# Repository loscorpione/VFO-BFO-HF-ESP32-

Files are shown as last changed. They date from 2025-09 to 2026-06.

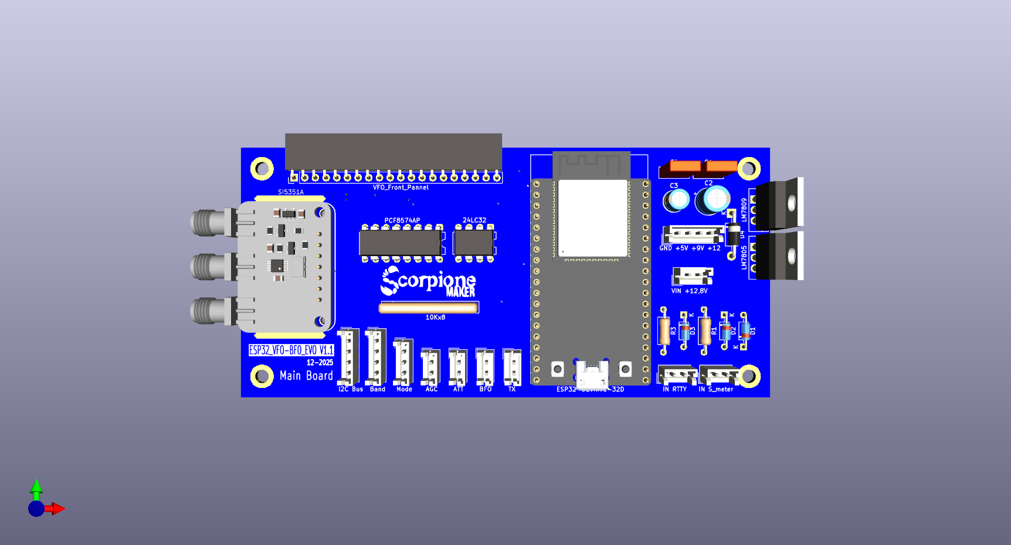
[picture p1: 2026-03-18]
VFO BFO Si5351 Circuit/VFO BFO Si5351 - Main Board/Immage/Mainboard.png

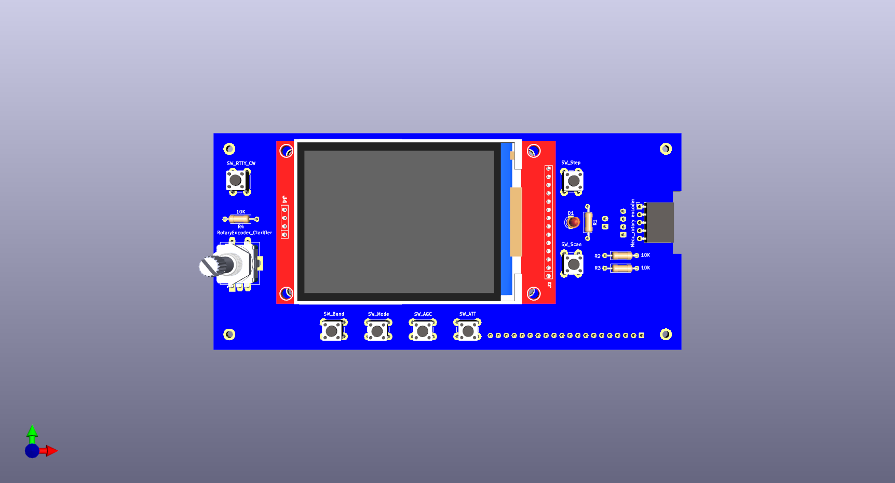
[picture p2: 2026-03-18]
VFO BFO Si5351 Circuit/VFO BFO Si5351 - Front Pannel/Immagin/Front Pannel.png

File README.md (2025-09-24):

VFO Basato su Si5351 e gestito da un ESP32 Devkit V1 attualmente il progetto è in costruzione.

Pensato principalmente per un ricevitore ma non è detto che in futuro venga implementata la funzione di trasmissione.

il progetto definitivo dovrà prevedere:
  -VFO con IF 455Khz 
  -BFO per la demodulazione di LSB, USB, CW con regolazione del "pitch" per un migliore adattamento
  -Uscita binaria a 2 bit indicante la modalità LSB, USB, CW, AM
  -Uscita binaria a 4 bit indicante la banda utilizzata per la selezione dell'opportuno BPF.
  -Eventuale decodifica per RTTY, CW on board
  -Memorizzazione su eeprom esterna o Fram 
  -Web server per la gestione remota tramite wi-fi ed eventuale proiezione in rete

I comandi sono:
  -ENCODER: come selettore di frequenza.
  -STEP: per cambio frequenza (10Hz, 100Hz, 1KHz, 10KHZ) con indicazione su display.
  -BAND: per la selezione della banda con indicazione su display delle bande radioamatoriali e non.
  -MODE: seleziona il tipo di demodulazione, con indicazione su pin binaria.
  -ATT: selettore attenuatore

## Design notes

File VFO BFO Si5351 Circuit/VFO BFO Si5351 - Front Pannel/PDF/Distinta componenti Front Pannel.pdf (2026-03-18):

Reference | Qty | Value | Footprint
D1 | | 1 LED | LED_THT:LED_D3.0mm
J1 | | 1 LED | Connector_JST:JST_EH_B2B-EH-A_1x02_P2.50mm_Vertical
J2 | | 1 Optical Rotary Encoder | Connector_JST:JST_EH_B4B-EH-A_1x04_P2.50mm_Vertical
J3 | | 1 Mecc_rotary encoder | Connector_PinSocket_2.54mm:PinSocket_1x05_P2.54mm_Horizontal
J4 | | 1 VFO_Front_Pannel | Connector_PinHeader_2.54mm:PinHeader_1x20_P2.54mm_Vertical
R1 | | 1 R=Vled-2/20mA | Resistor_THT:R_Axial_DIN0207_L6.3mm_D2.5mm_P10.16mm_Horizontal
R2,R3,R4 | | 3 10K | Resistor_THT:R_Axial_DIN0207_L6.3mm_D2.5mm_P10.16mm_Horizontal
SW1 | | 1 RotaryEncoder_Clarifier | -Rotary_Encoder:RotaryEncoder_Alps_EC12E-Switch_Vertical_H20mm
SW2 | | 1 SW_Band | Button_Switch_THT:SW_PUSH_6mm
SW3 | | 1 SW_Mode | Button_Switch_THT:SW_PUSH_6mm
SW4 | | 1 SW_AGC | Button_Switch_THT:SW_PUSH_6mm
SW5 | | 1 SW_ATT | Button_Switch_THT:SW_PUSH_6mm
SW6 | | 1 SW_Scan | Button_Switch_THT:SW_PUSH_6mm
SW7 | | 1 SW_Step | Button_Switch_THT:SW_PUSH_6mm
SW8 | | 1 SW_RTTY_CW | Button_Switch_THT:SW_PUSH_6mm
U1 | | 1 Ili9341_Module_TFT_320x240_Touch | -Display_Graphic:DISPLAY_TFT_ILI9341_2.8

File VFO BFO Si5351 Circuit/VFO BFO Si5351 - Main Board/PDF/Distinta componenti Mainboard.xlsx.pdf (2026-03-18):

Reference | Qty | Value | Footprint
C1,C4 | | 2 100nF | Capacitor_THT:C_Rect_L7.0mm_W2.5mm_P5.00mm
C2 | | 1 220uF 16V | Capacitor_THT:CP_Radial_D6.3mm_P2.50mm
C3 | | 1 100uF 10V | Capacitor_THT:CP_Radial_D5.0mm_P2.00mm
D1 | | 1 1N4148 | Diode_THT:D_DO-35_SOD27_P7.62mm_Horizontal
D2,D3 | | 2 DZ 3.3V | Diode_THT:D_DO-35_SOD27_P7.62mm_Horizontal
D4 | | 1 1N4007 | Diode_THT:D_DO-41_SOD81_P10.16mm_Horizontal
J1 | | 1 I2C Bus | Connector_JST:JST_EH_B4B-EH-A_1x04_P2.50mm_Vertical
J2 | | 1 Band | Connector_JST:JST_EH_B4B-EH-A_1x04_P2.50mm_Vertical
J3 | | 1 Mode | Connector_JST:JST_EH_B3B-EH-A_1x03_P2.50mm_Vertical
J4 | | 1 AGC | Connector_JST:JST_EH_B2B-EH-A_1x02_P2.50mm_Vertical
J5 | | 1 ATT | Connector_JST:JST_EH_B2B-EH-A_1x02_P2.50mm_Vertical
J6 | | 1 BFO | Connector_JST:JST_EH_B2B-EH-A_1x02_P2.50mm_Vertical
J7 | | 1 TX | Connector_JST:JST_EH_B2B-EH-A_1x02_P2.50mm_Vertical
J8 | | 1 IN RTTY | Connector_JST:JST_EH_B2B-EH-A_1x02_P2.50mm_Vertical
J9 | | 1 IN S_meter | Connector_JST:JST_EH_B2B-EH-A_1x02_P2.50mm_Vertical
J10 | | 1 VIN +12,8V | Connector_JST:JST_EH_B2B-EH-A_1x02_P2.50mm_Vertical
J11 | | 1 GND +5V +9V +12 | Connector_JST:JST_EH_B4B-EH-A_1x04_P2.50mm_Vertical
J12 | | 1 Front_Pannel | Connector_PinHeader_2.54mm:PinHeader_1x20_P2.54mm_Vertical
M1 | | 1 Si5351A module | Periferial_Module:si5351a_Module
R1,R3 | | 2 1K | Resistor_THT:R_Axial_DIN0207_L6.3mm_D2.5mm_P10.16mm_Horizontal
RN1 | | 1 10Kx8 | Resistor_THT:R_Array_SIP9
U1 | | 1 ESP32-DEVKITC-32D | -ESP32_Module:MODULE_ESP32-DEVKITC-32D
U2 | | 1 PCF8574AP | Package_DIP:DIP-16_W7.62mm
U3 | | 1 LM7809 | Package_TO_SOT_THT:TO-220-3_Vertical
U4 | | 1 LM7805 | Package_TO_SOT_THT:TO-220-3_Vertical
U5 | | 1 24LC32 | Package_DIP:DIP-8_W7.62mm

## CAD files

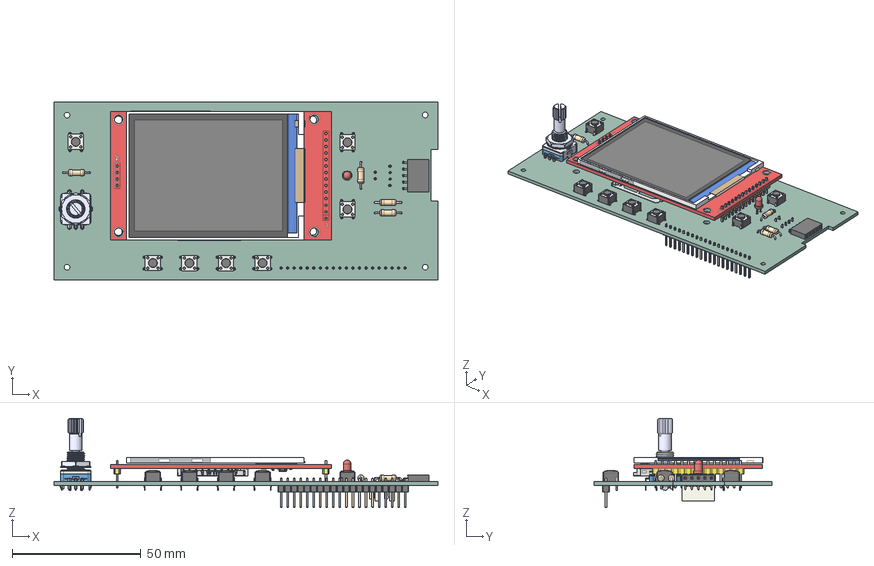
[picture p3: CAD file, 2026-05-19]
VFO BFO Si5351 Circuit/VFO BFO Si5351 - Front Pannel/Front Pannel.step
149.4 x 69.2 x 34.7 mm
R_Axial_DIN0207_L6.3mm_D2.5mm_P10.16mm_Horizontal x 4
LED_D3.0mm
SW_PUSH_6mm x 7
PinSocket_1x05_P2.54mm_Horizontal
EC11-Shaft-K
EC11-Housing-THT
2.8 LCD TFT Module - Without Glass
0603 Resistor x 6
0603 Capacitor x 2
SOT23-3 x 2
2.8in TFT(Without Glass)- Tucked Cable
JST_EH_B2B-EH-A_1x02_P2.50mm_Vertical
PinHeader_1x20_P2.54mm_Vertical
JST_EH_B4B-EH-A_1x04_P2.50mm_Vertical
Front Pannel_PCB

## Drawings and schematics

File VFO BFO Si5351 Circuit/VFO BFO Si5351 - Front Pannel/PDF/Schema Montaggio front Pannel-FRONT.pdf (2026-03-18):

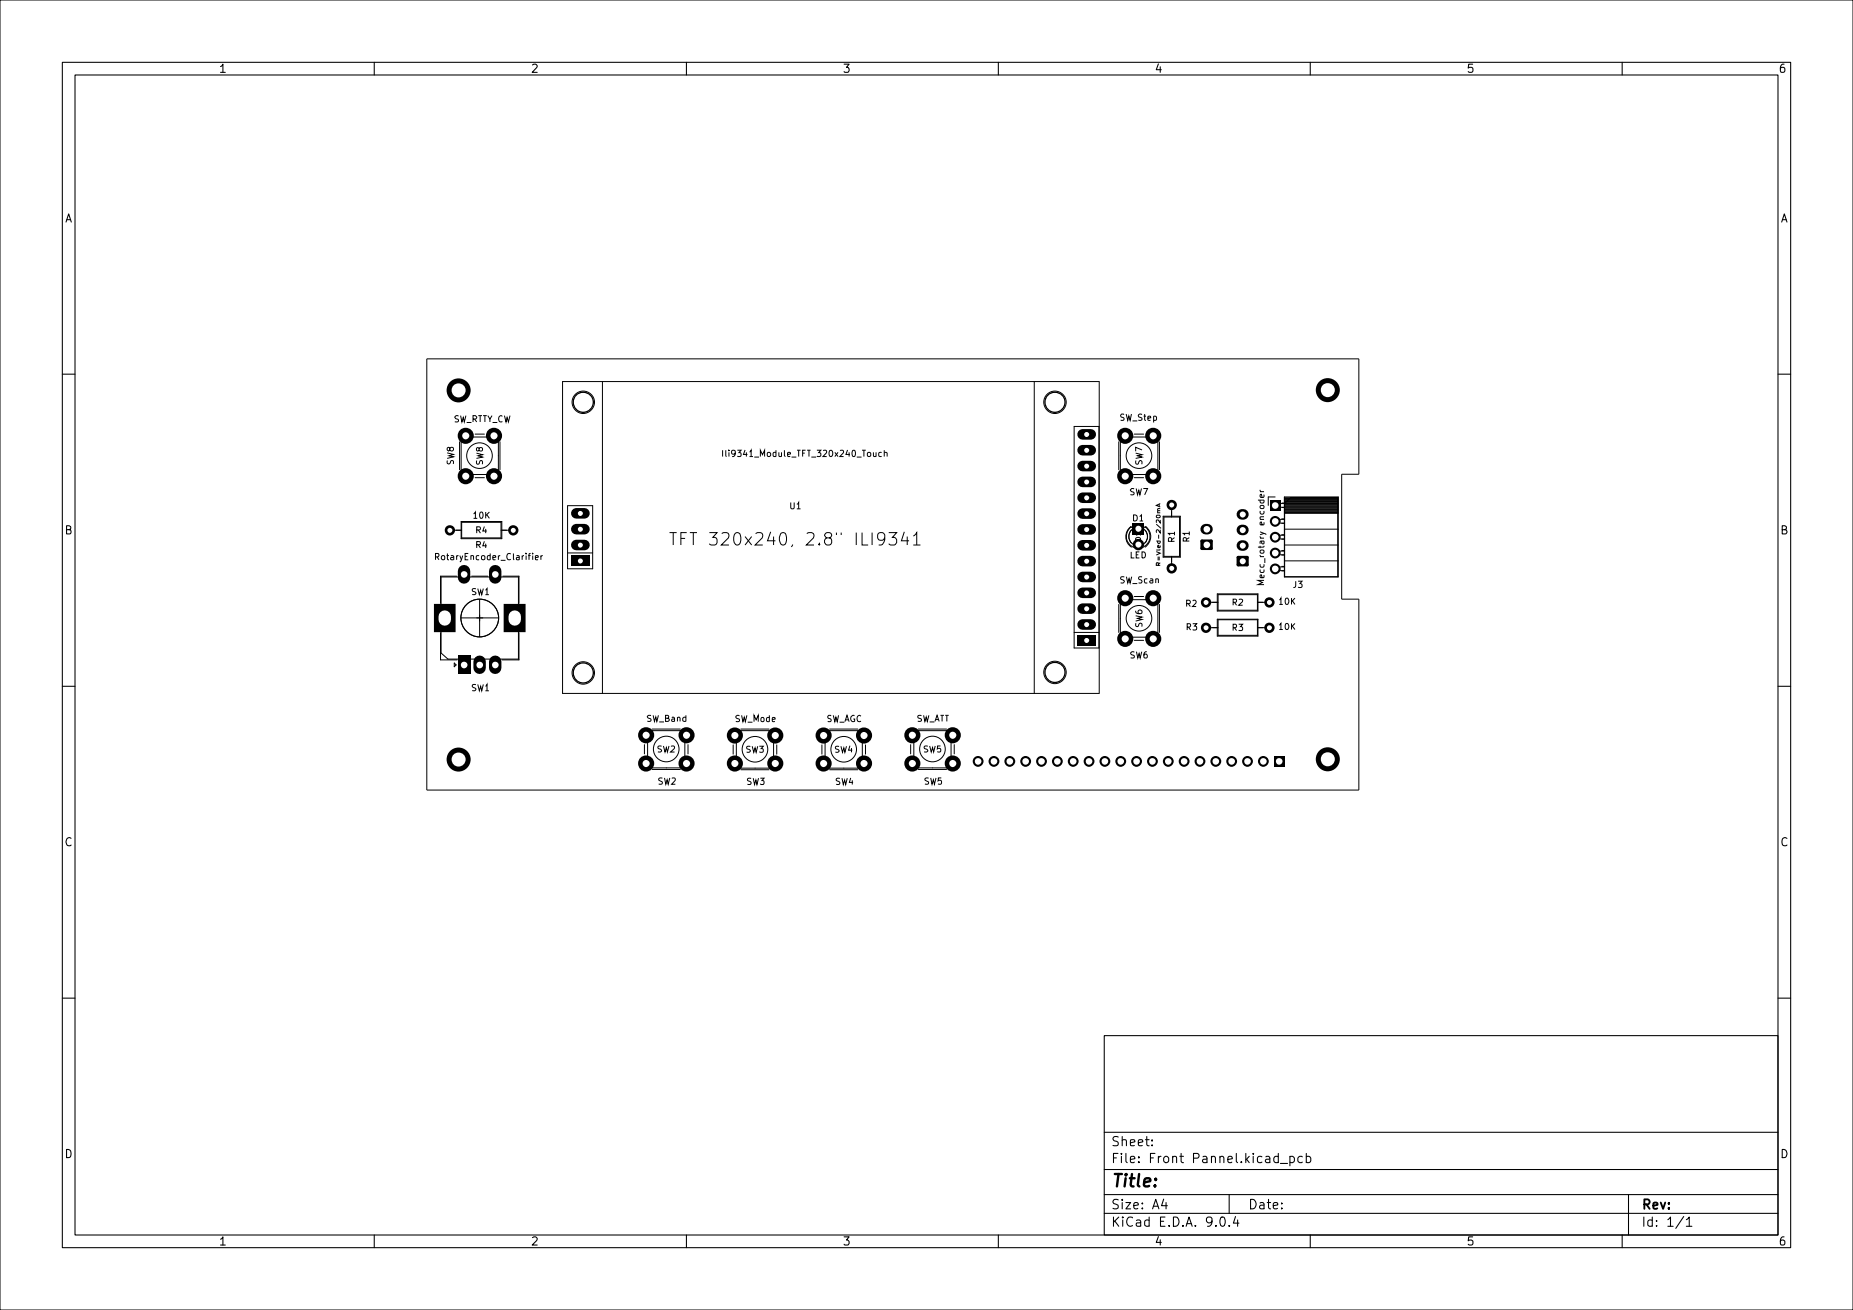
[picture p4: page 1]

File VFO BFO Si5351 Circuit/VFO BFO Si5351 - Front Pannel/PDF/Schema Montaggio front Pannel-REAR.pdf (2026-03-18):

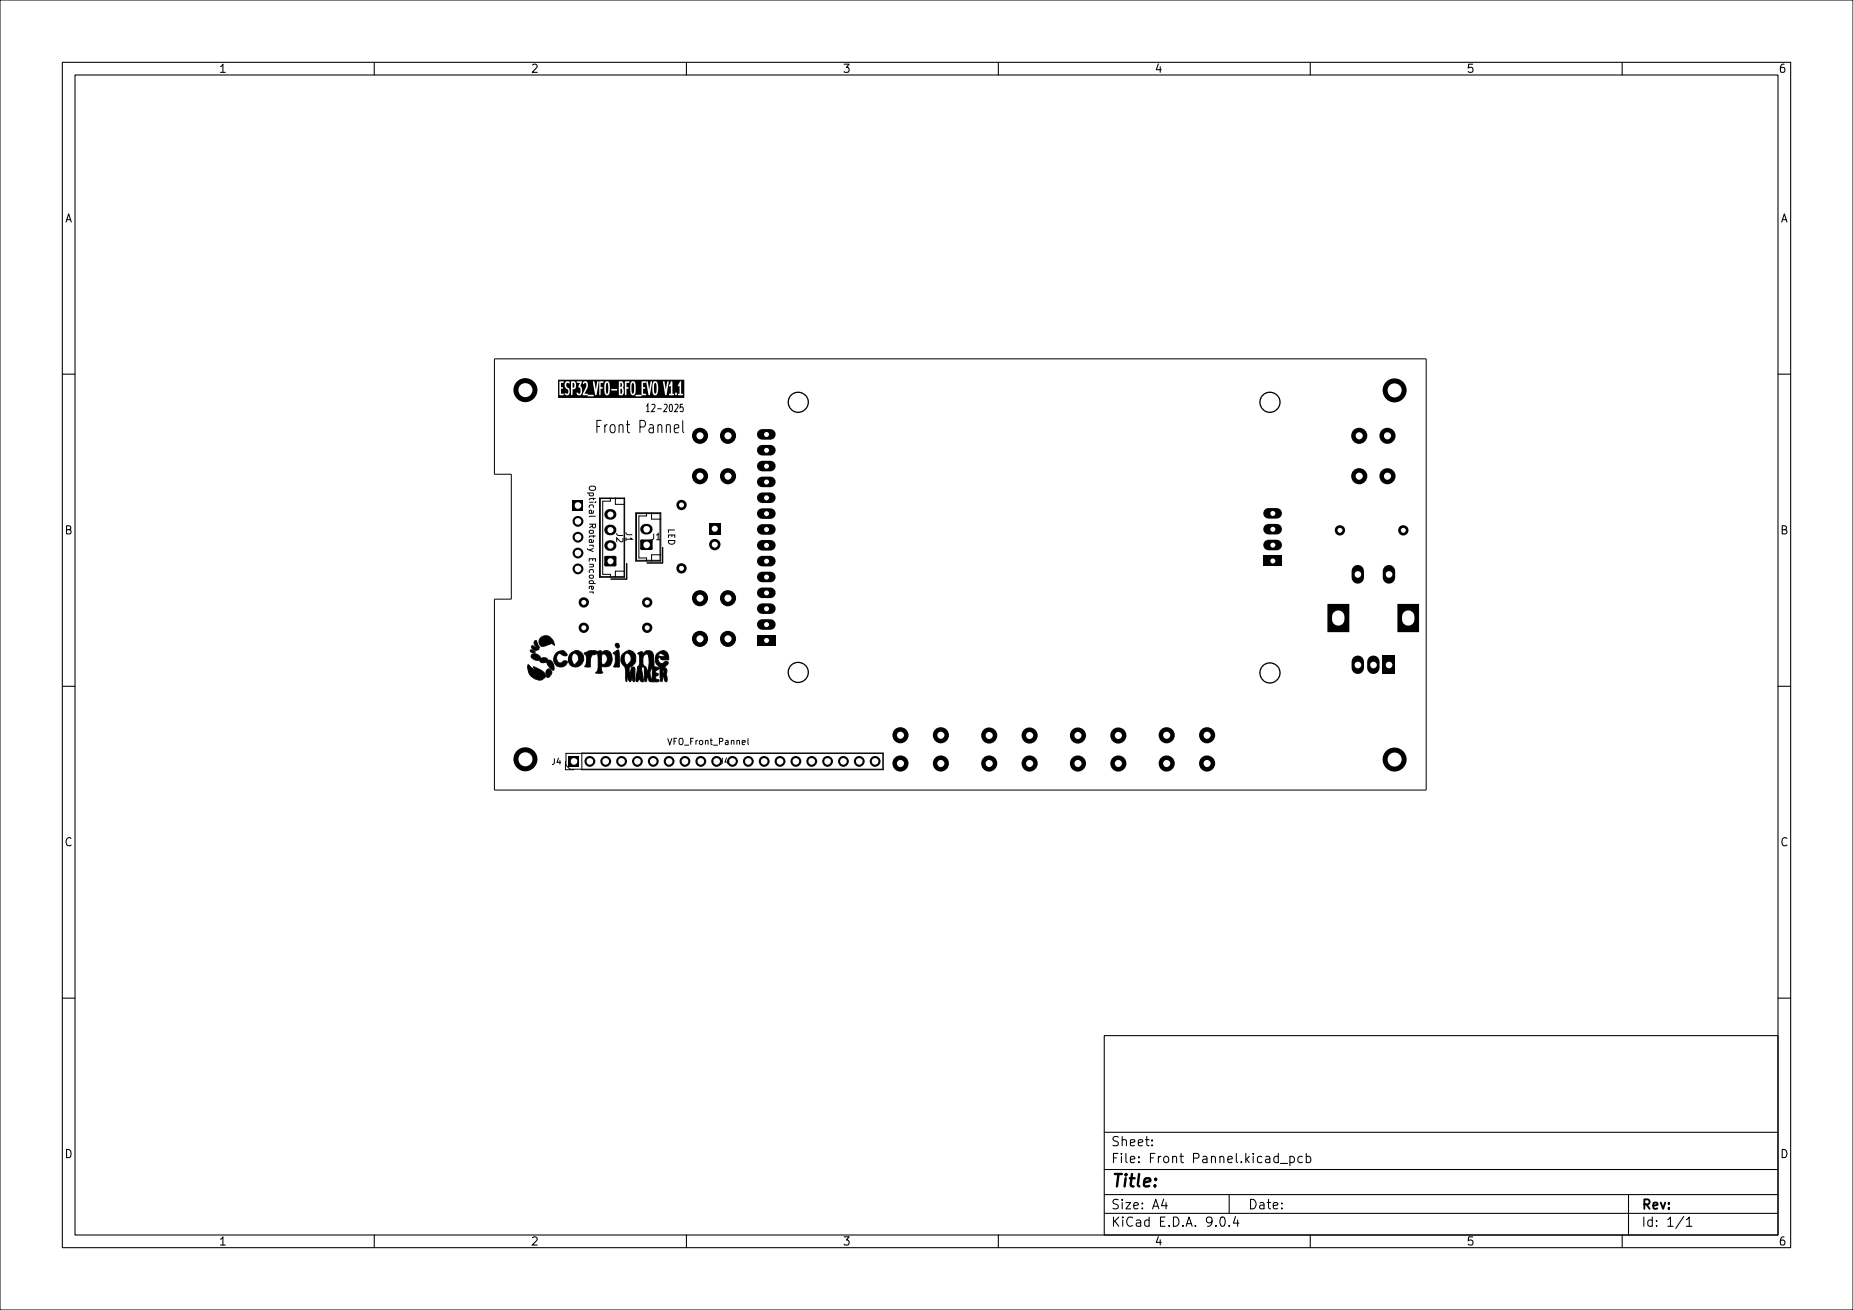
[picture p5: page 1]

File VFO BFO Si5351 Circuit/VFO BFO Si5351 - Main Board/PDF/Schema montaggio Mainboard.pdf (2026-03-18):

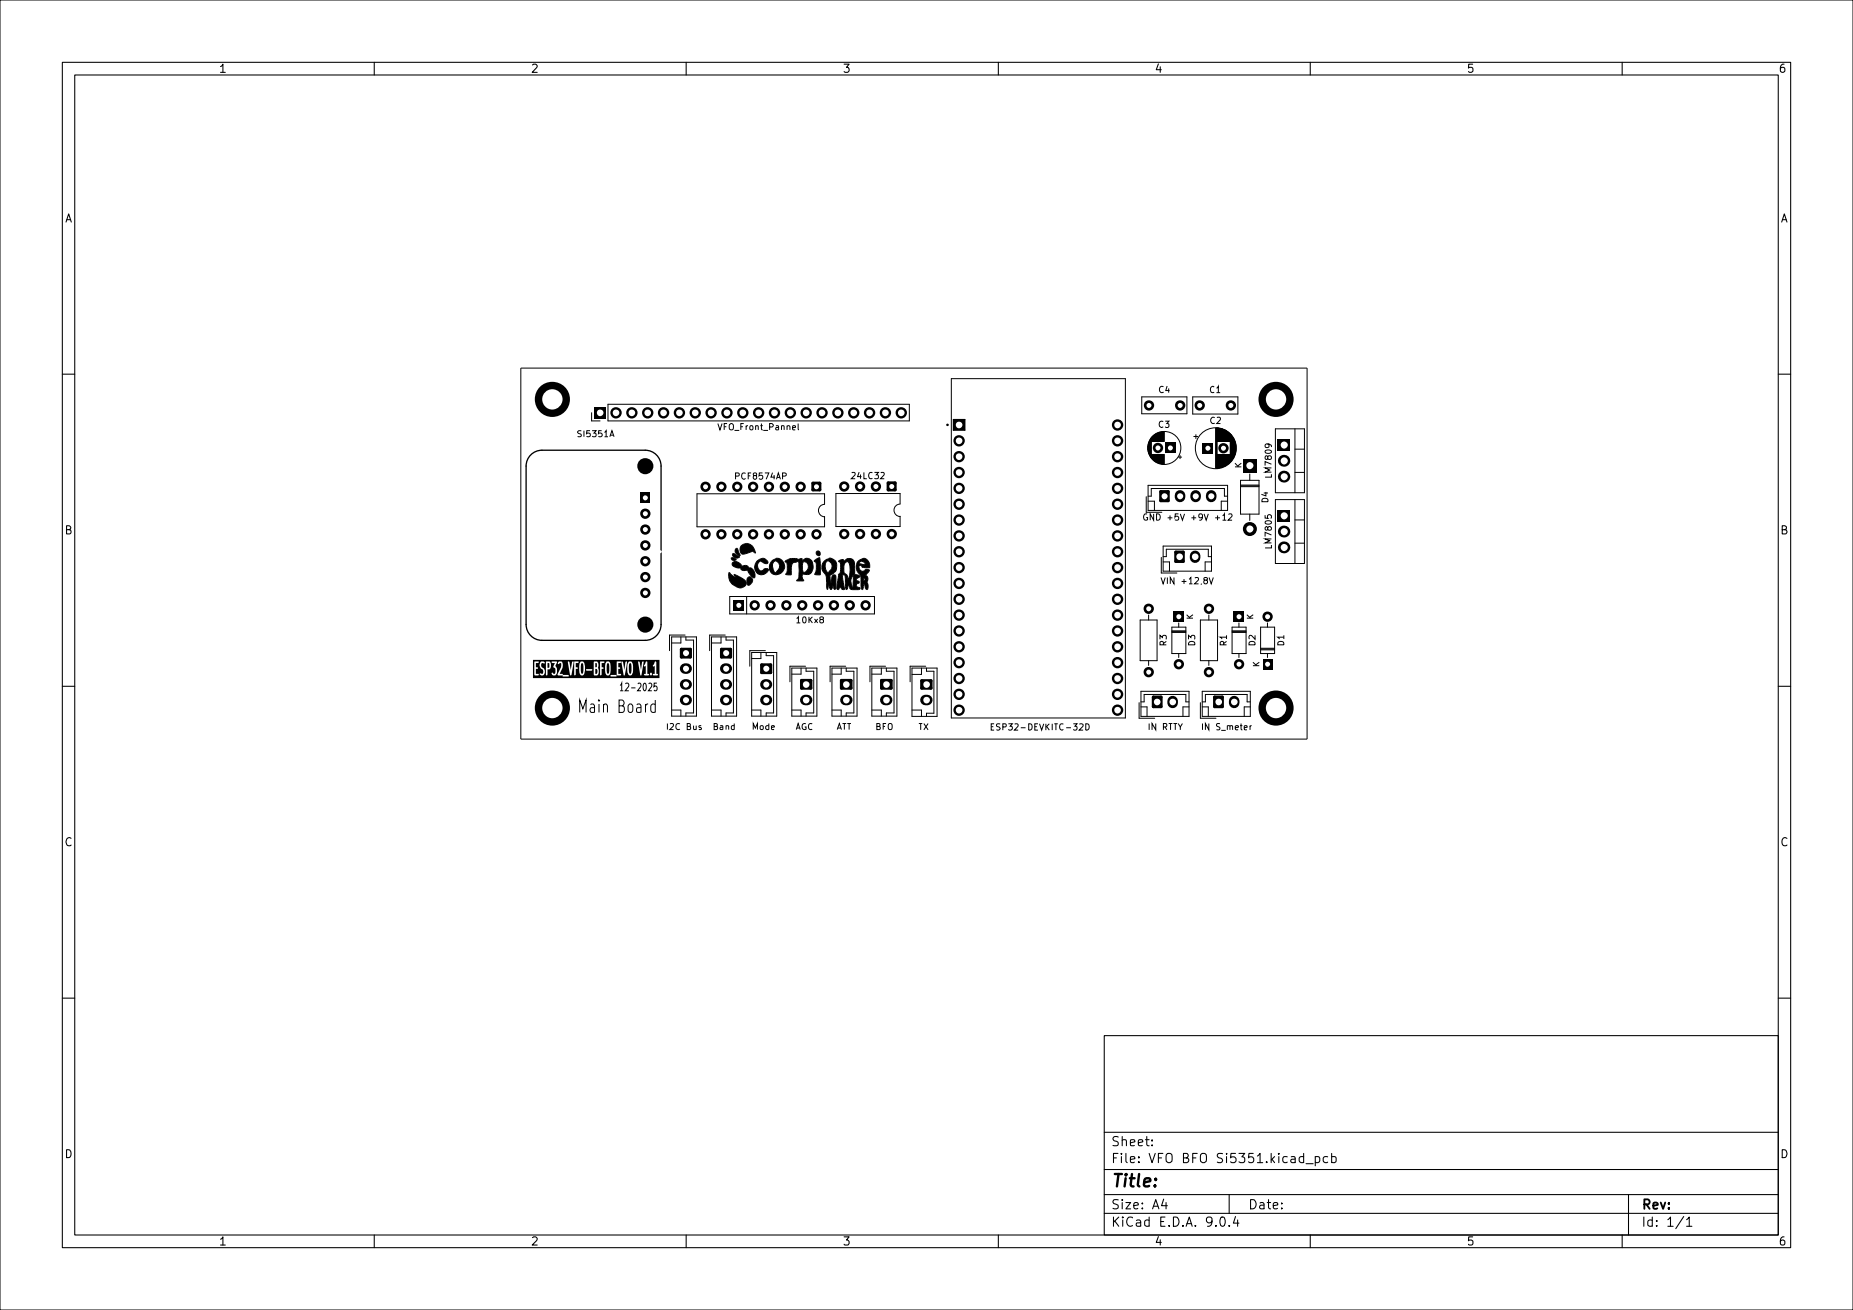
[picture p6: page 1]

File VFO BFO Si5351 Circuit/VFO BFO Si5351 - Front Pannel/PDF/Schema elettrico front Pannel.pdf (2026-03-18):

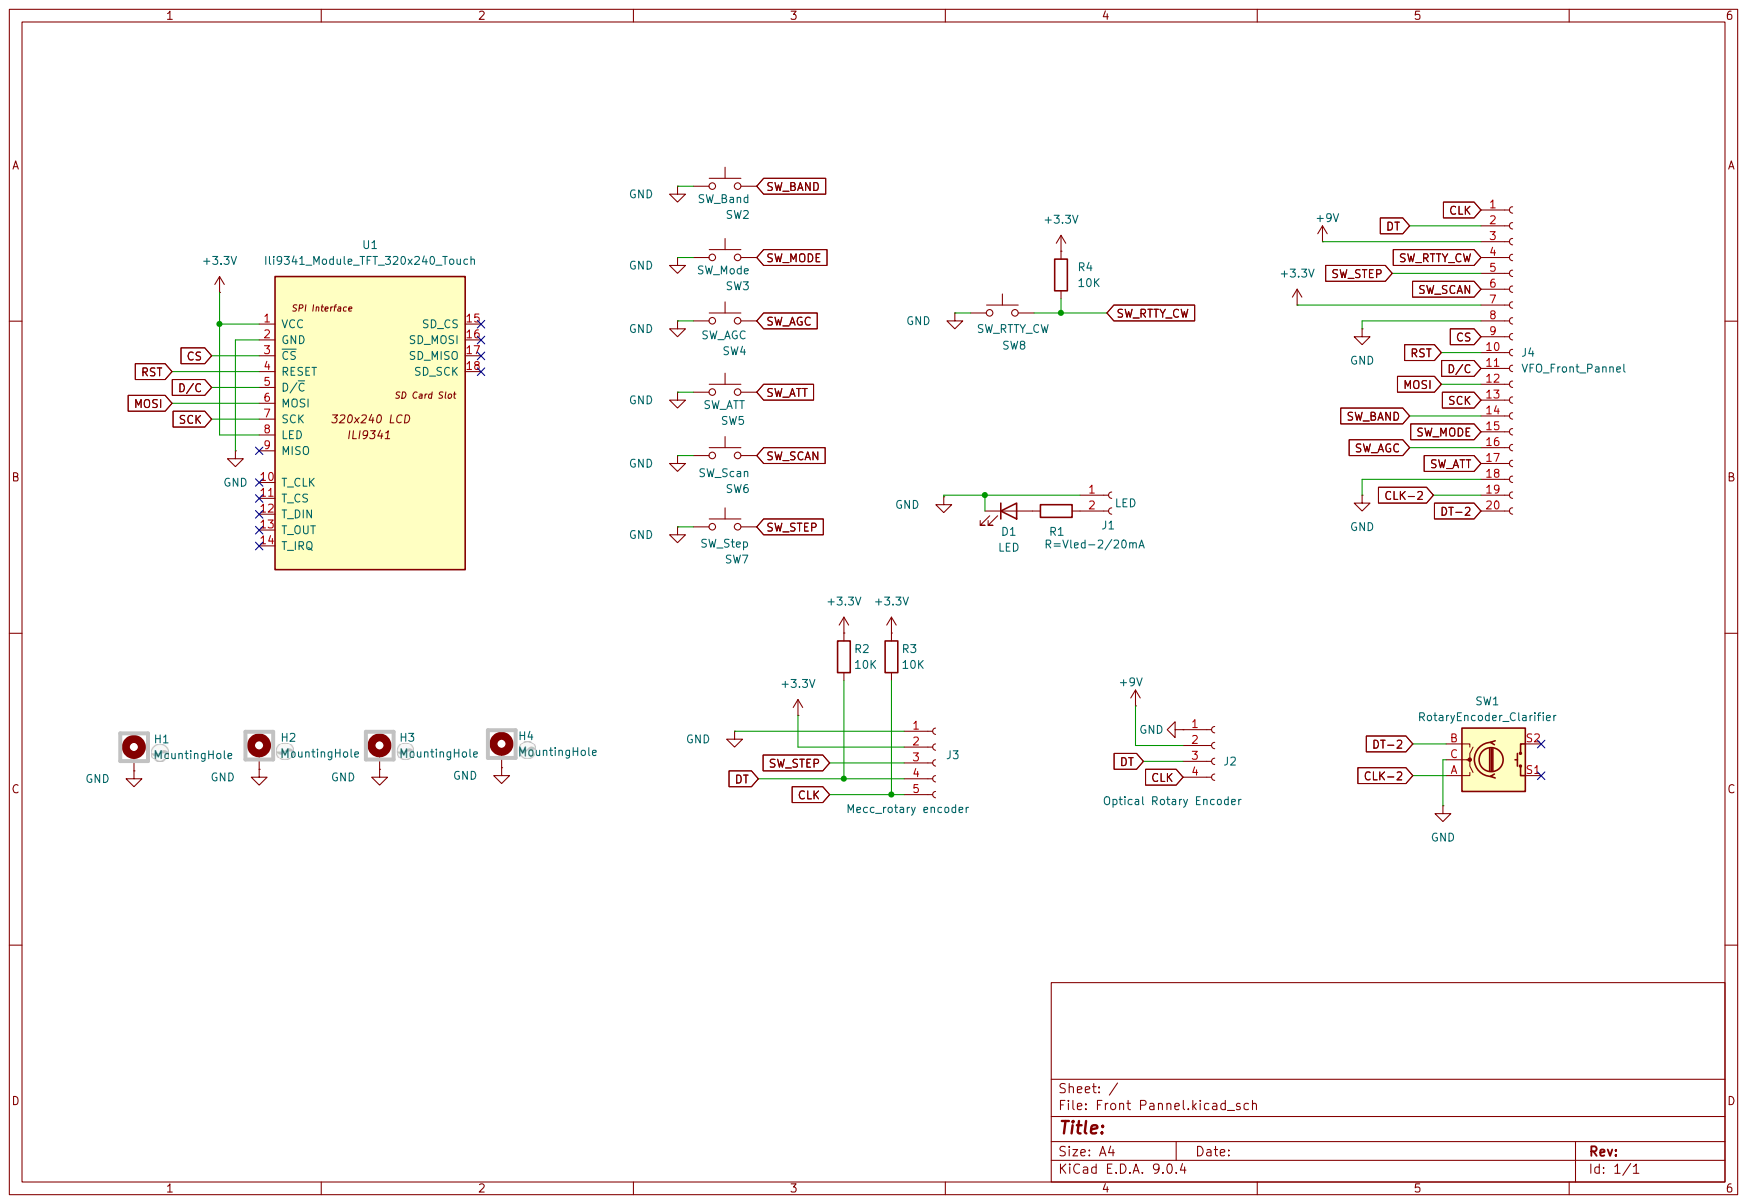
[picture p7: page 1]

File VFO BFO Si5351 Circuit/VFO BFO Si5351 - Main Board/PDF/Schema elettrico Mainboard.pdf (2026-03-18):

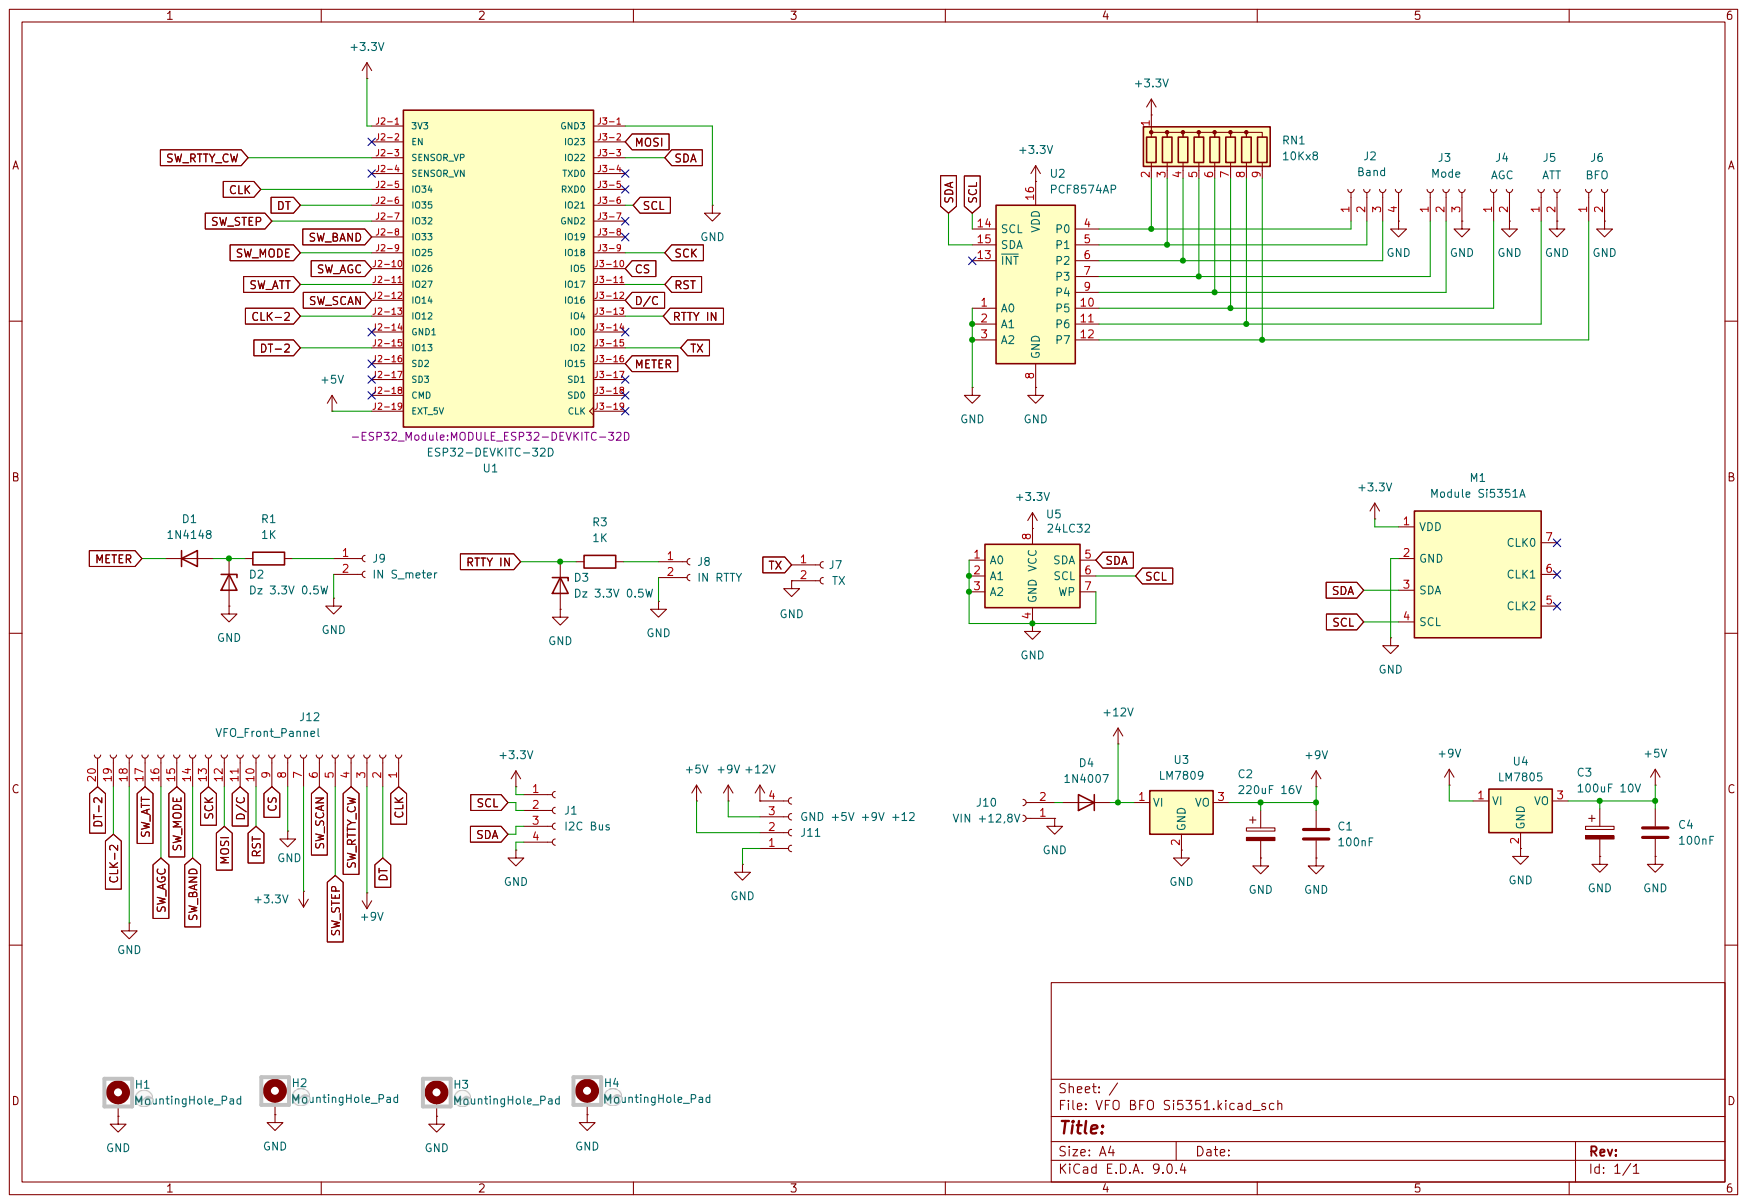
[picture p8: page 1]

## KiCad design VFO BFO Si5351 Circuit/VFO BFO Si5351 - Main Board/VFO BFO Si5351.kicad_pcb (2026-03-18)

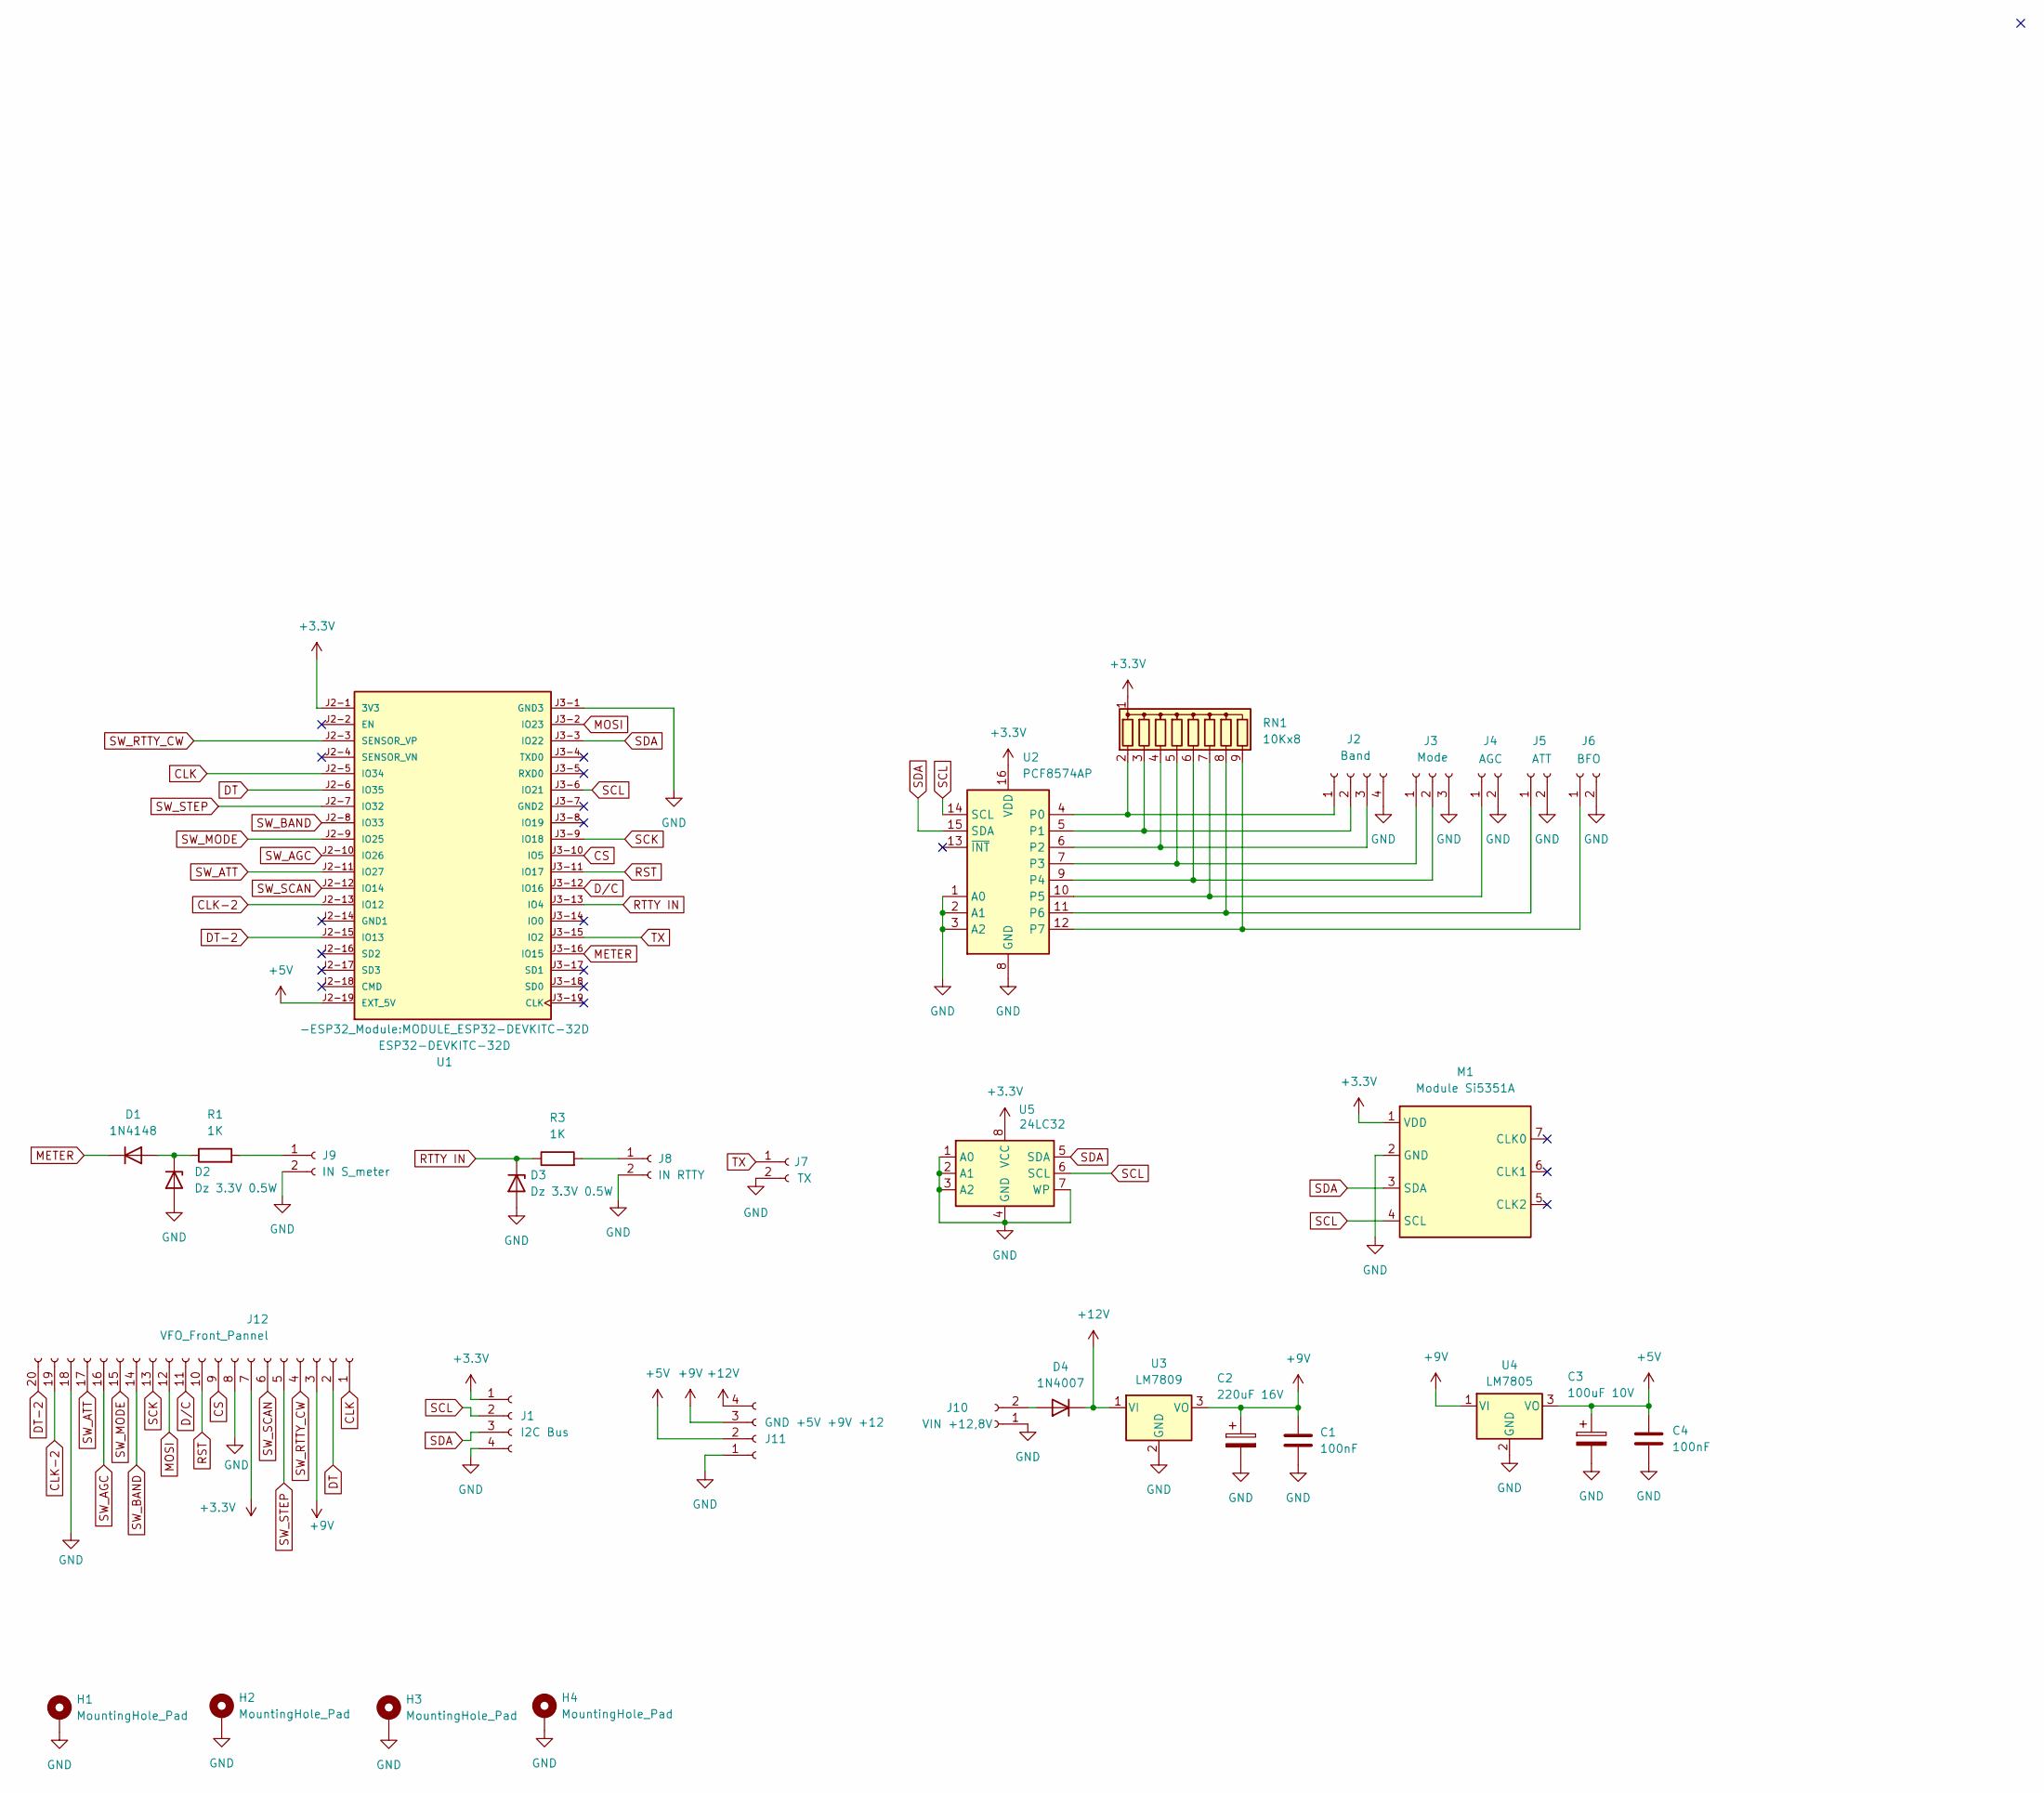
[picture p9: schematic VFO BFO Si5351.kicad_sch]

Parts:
C1, C4: 100nF; C_Rect_L7.0mm_W2.5mm_P5.00mm
C2: 220uF 16V; CP_Radial_D6.3mm_P2.50mm
C3: 100uF 10V; CP_Radial_D5.0mm_P2.00mm
D1: 1N4148; D_DO-35_SOD27_P7.62mm_Horizontal
D2, D3: Dz 3.3V 0.5W; D_DO-35_SOD27_P7.62mm_Horizontal
D4: 1N4007; D_DO-41_SOD81_P10.16mm_Horizontal
H1, H2, H3, H4: MountingHole_Pad; MountingHole_3.2mm_M3_DIN965_Pad_TopBottom
J1: I2C Bus; JST_EH_B4B-EH-A_1x04_P2.50mm_Vertical
J2: Band; JST_EH_B4B-EH-A_1x04_P2.50mm_Vertical
J3: Mode; JST_EH_B3B-EH-A_1x03_P2.50mm_Vertical
J4: AGC; JST_EH_B2B-EH-A_1x02_P2.50mm_Vertical
J5: ATT; JST_EH_B2B-EH-A_1x02_P2.50mm_Vertical
J6: BFO; JST_EH_B2B-EH-A_1x02_P2.50mm_Vertical
J7: TX; JST_EH_B2B-EH-A_1x02_P2.50mm_Vertical
J8: IN RTTY; JST_EH_B2B-EH-A_1x02_P2.50mm_Vertical
J9: IN S_meter; JST_EH_B2B-EH-A_1x02_P2.50mm_Vertical
J10: VIN +12,8V; JST_EH_B2B-EH-A_1x02_P2.50mm_Vertical
J11: GND +5V +9V +12; JST_EH_B4B-EH-A_1x04_P2.50mm_Vertical
J12: VFO_Front_Pannel; PinHeader_1x20_P2.54mm_Vertical
M1: Module Si5351A; si5351a_Module
R1, R3: 1K; R_Axial_DIN0207_L6.3mm_D2.5mm_P10.16mm_Horizontal
RN1: 10Kx8; R_Array_SIP9
U1: ESP32-DEVKITC-32D; MODULE_ESP32-DEVKITC-32D; PARTREV V4
U2: PCF8574AP; DIP-16_W7.62mm
U3: LM7809; TO-220-3_Vertical
U4: LM7805; TO-220-3_Vertical
U5: 24LC32; DIP-8_W7.62mm

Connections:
+3.3V: J1.1, J12.7, M1.1 (VDD), RN1.1 (common), U1.J2-1 (3V3), U2.16 (VDD), U5.8 (VCC)
+5V: C3.1, C4.1, J11.2, U1.J2-19 (EXT_5V), U4.3 (VO)
+9V: C1.1, C2.1, J11.3, J12.3, U3.3 (VO), U4.1 (VI)
+12V: D4.1 (K), J11.4, U3.1 (VI)
CLK: J12.1, U1.J2-5 (IO34)
CLK-2: J12.19, U1.J2-13 (IO12)
CS: J12.9, U1.J3-10 (IO5)
DT: J12.2, U1.J2-6 (IO35)
DT-2: J12.20, U1.J2-15 (IO13)
D/C: J12.11, U1.J3-12 (IO16)
GND: C1.2, C2.2, C3.2, C4.2, D2.2 (A), D3.2 (A), H1.1, H2.1, H3.1, H4.1, J1.4, J2.4, J3.3, J4.2, J5.2, J6.2, J7.2, J8.2, J9.2, J10.1, J11.1, J12.8, J12.18, M1.2 (GND), U1.J3-1 (GND3), U2.1 (A0), U2.2 (A1), U2.3 (A2), U2.8 (GND), U3.2 (GND), U4.2 (GND), U5.1 (A0), U5.2 (A1), U5.3 (A2), U5.4 (GND), U5.7 (WP)
METER: D1.1 (K), U1.J3-16 (IO15)
MOSI: J12.12, U1.J3-2 (IO23)
unnamed: D1.2 (A), D2.1 (K), R1.1
unnamed: D4.2 (A), J10.2
unnamed: J2.1, RN1.2 (R1), U2.4 (P0)
unnamed: J2.2, RN1.3 (R2), U2.5 (P1)
unnamed: J2.3, RN1.4 (R3), U2.6 (P2)
unnamed: J3.1, RN1.5 (R4), U2.7 (P3)
unnamed: J3.2, RN1.6 (R5), U2.9 (P4)
unnamed: J4.1, RN1.7 (R6), U2.10 (P5)
unnamed: J5.1, RN1.8 (R7), U2.11 (P6)
unnamed: J6.1, RN1.9 (R8), U2.12 (P7)
unnamed: J8.1, R3.2
unnamed: J9.1, R1.2
RST: J12.10, U1.J3-11 (IO17)
RTTY IN: D3.1 (K), R3.1, U1.J3-13 (IO4)
SCK: J12.13, U1.J3-9 (IO18)
SCL: J1.2, M1.4 (SCL), U1.J3-6 (IO21), U2.14 (SCL), U5.6 (SCL)
SDA: J1.3, M1.3 (SDA), U1.J3-3 (IO22), U2.15 (SDA), U5.5 (SDA)
SW_AGC: J12.16, U1.J2-10 (IO26)
SW_ATT: J12.17, U1.J2-11 (IO27)
SW_BAND: J12.14, U1.J2-8 (IO33)
SW_MODE: J12.15, U1.J2-9 (IO25)
SW_RTTY_CW: J12.4, U1.J2-3 (SENSOR_VP)
SW_SCAN: J12.6, U1.J2-12 (IO14)
SW_STEP: J12.5, U1.J2-7 (IO32)
TX: J7.1, U1.J3-15 (IO2)

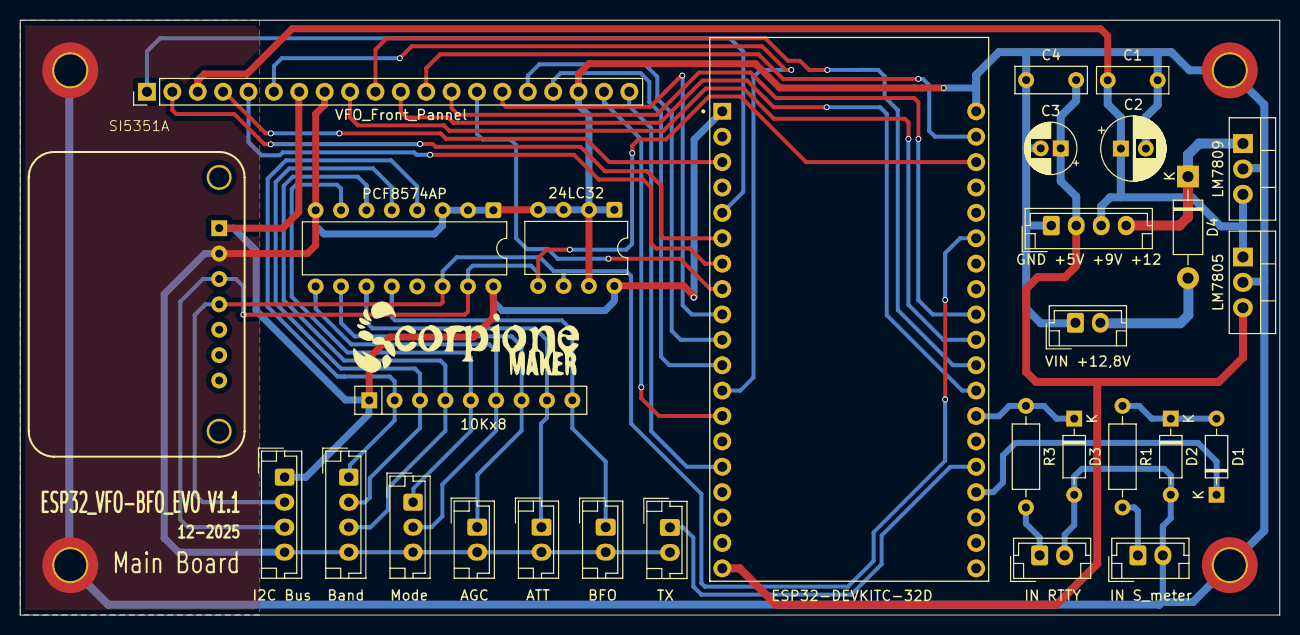
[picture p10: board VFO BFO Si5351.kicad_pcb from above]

Board: 2 copper layers, 126.0 x 59.5 mm, 33 parts (0 on the bottom side), 38 nets.

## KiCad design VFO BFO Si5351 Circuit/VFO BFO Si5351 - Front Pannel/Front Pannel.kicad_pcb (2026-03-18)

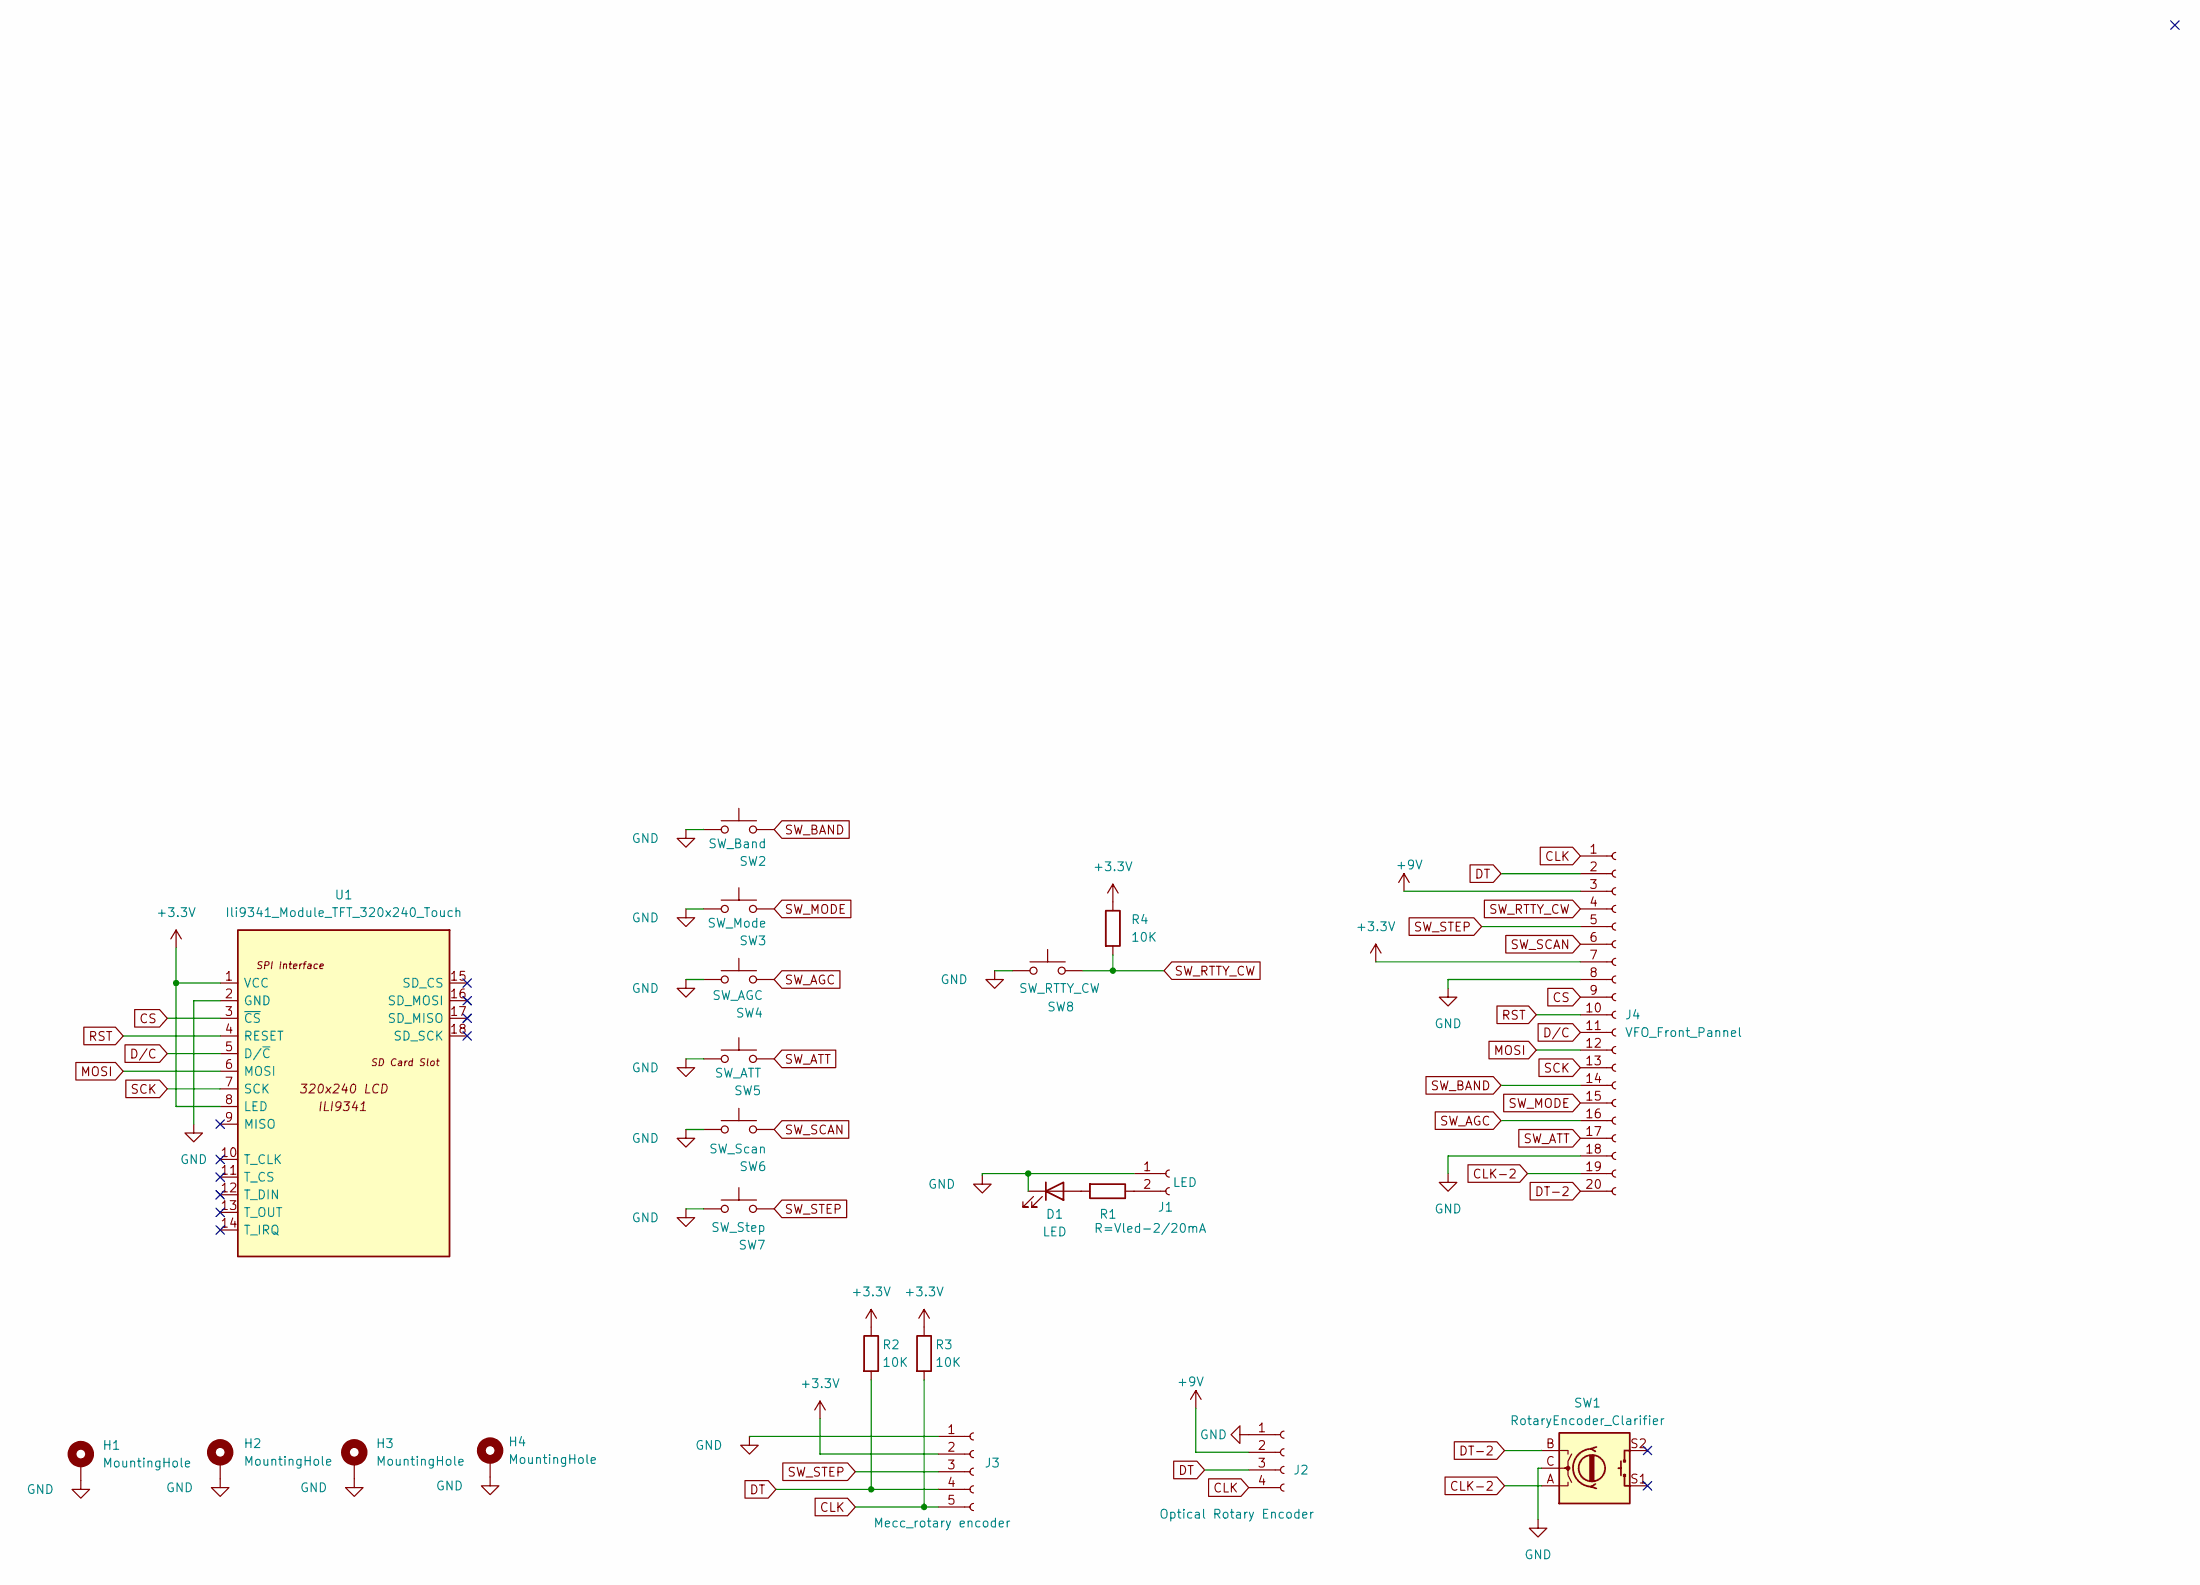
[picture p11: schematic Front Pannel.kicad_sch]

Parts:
D1: LED; LED_D3.0mm
H1, H2, H3, H4: MountingHole; MountingHole_3.2mm_M3_DIN965_Pad_TopBottom
J1: LED; JST_EH_B2B-EH-A_1x02_P2.50mm_Vertical
J2: Optical Rotary Encoder; JST_EH_B4B-EH-A_1x04_P2.50mm_Vertical
J3: Mecc_rotary encoder; PinSocket_1x05_P2.54mm_Horizontal
J4: VFO_Front_Pannel; PinHeader_1x20_P2.54mm_Vertical
R1: R=Vled-2/20mA; R_Axial_DIN0207_L6.3mm_D2.5mm_P10.16mm_Horizontal
R2, R3, R4: 10K; R_Axial_DIN0207_L6.3mm_D2.5mm_P10.16mm_Horizontal
SW1: RotaryEncoder_Clarifier; RotaryEncoder_Alps_EC12E-Switch_Vertical_H20mm
SW2: SW_Band; SW_PUSH_6mm
SW3: SW_Mode; SW_PUSH_6mm
SW4: SW_AGC; SW_PUSH_6mm
SW5: SW_ATT; SW_PUSH_6mm
SW6: SW_Scan; SW_PUSH_6mm
SW7: SW_Step; SW_PUSH_6mm
SW8: SW_RTTY_CW; SW_PUSH_6mm
U1: Ili9341_Module_TFT_320x240_Touch; DISPLAY_TFT_ILI9341_2.8

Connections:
+3.3V: J3.2, J4.7, R2.1, R3.1, R4.1, U1.1 (VCC), U1.8 (LED)
+9V: J2.2, J4.3
CLK: J2.4, J3.5, J4.1, R3.2
CLK-2: J4.19, SW1.A
CS: J4.9, U1.3 (~CS)
DT: J2.3, J3.4, J4.2, R2.2
DT-2: J4.20, SW1.B
D/C: J4.11, U1.5 (D/~C)
GND: D1.1 (K), H1.1, H2.1, H3.1, H4.1, J1.1, J2.1, J3.1, J4.8, J4.18, SW1.C, SW2.1, SW3.1, SW4.1, SW5.1, SW6.1, SW7.1, SW8.1, U1.2 (GND)
MOSI: J4.12, U1.6 (MOSI)
unnamed: D1.2 (A), R1.2
unnamed: J1.2, R1.1
RST: J4.10, U1.4 (RESET)
SCK: J4.13, U1.7 (SCK)
SW_AGC: J4.16, SW4.2
SW_ATT: J4.17, SW5.2
SW_BAND: J4.14, SW2.2
SW_MODE: J4.15, SW3.2
SW_RTTY_CW: J4.4, R4.2, SW8.2
SW_SCAN: J4.6, SW6.2
SW_STEP: J3.3, J4.5, SW7.2

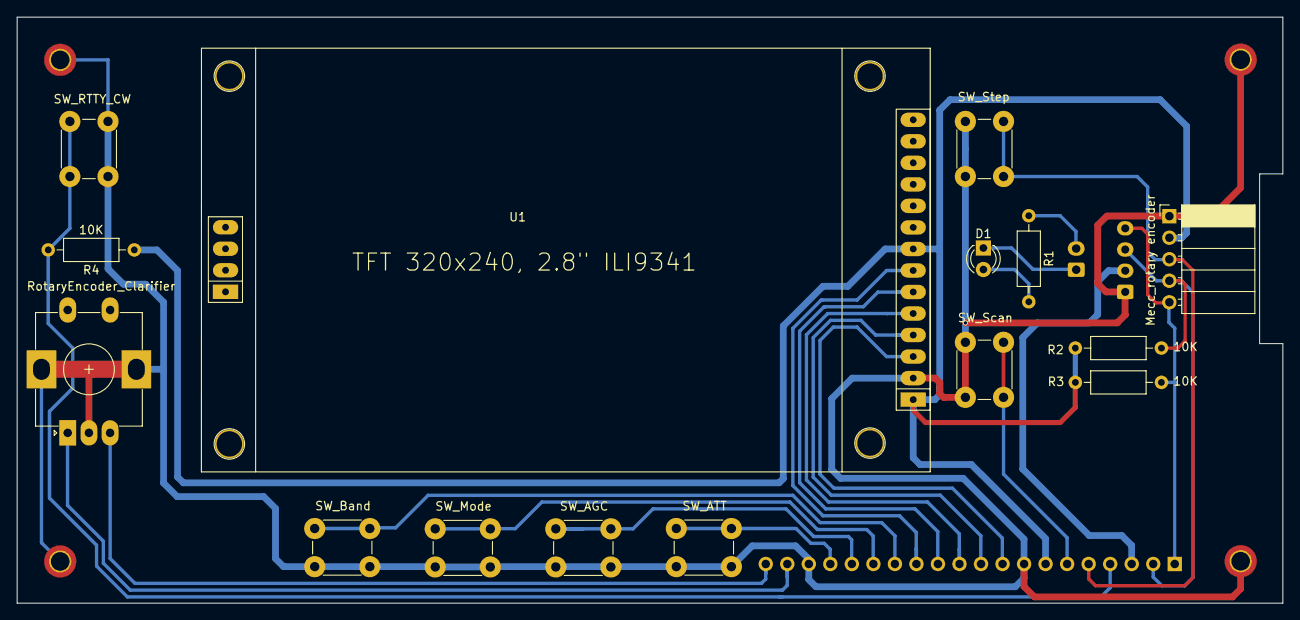
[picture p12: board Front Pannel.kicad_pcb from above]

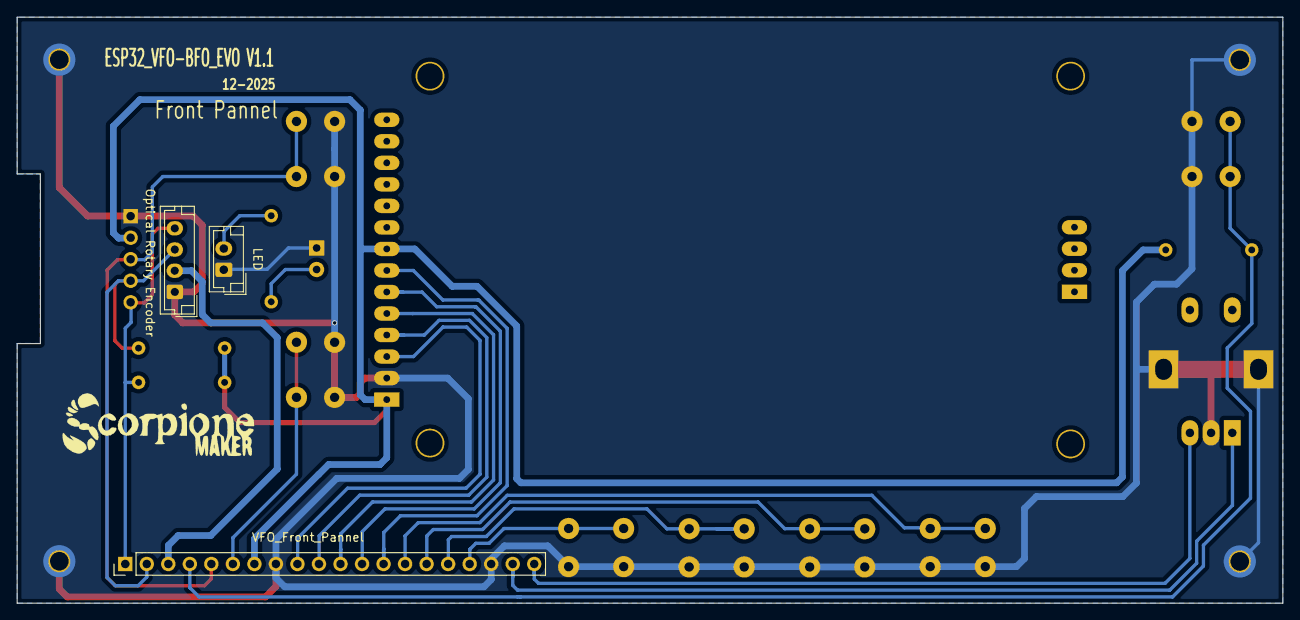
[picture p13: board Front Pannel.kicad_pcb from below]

Board: 2 copper layers, 149.4 x 69.2 mm, 22 parts (3 on the bottom side), 21 nets.

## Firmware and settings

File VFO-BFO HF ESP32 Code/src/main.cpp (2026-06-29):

#include <Arduino.h>
#include "config.h"
#include "display.h"
#include "VFO_BFO.h"
#include "PLL.h"
#include "bands.h"
#include "modes.h"
#include "s_meter.h"
#include "DigiOUT.h" 
#include "functions.h"
#include "EEPROM_manager.h"
#include "keypad.h"

void handleSerialCommands();
void calibrateSI5351(long calibration_factor);

// ============================================
// Variabile per calibrazione
// ============================================

int32_t currentCalibration = 0;

// ============================================
// Variabili globali
// ============================================

unsigned long vfoFrequency = 7000000 + IF_FREQUENCY;
unsigned long displayedFrequency = 7000000;
unsigned long step = 1000;
unsigned long minFreq = 1000000;
unsigned long maxFreq = 30000000;

// ============================================
// VARIABILI PER INSERIMENTO FREQUENZA
// ============================================

bool inputMode = false;
String inputDisplay = "";   // Per la visualizzazione (con punti)
String inputValue = "";     // Per il calcolo (senza punti)
unsigned long lastInputTime = 0;
const unsigned long INPUT_TIMEOUT = 5000;

// ============================================
// FUNZIONE CALIBRAZIONE SI5351 DA SERIALE
// ============================================

void handleSerialCommands() {
    if (Serial.available() > 0) {
        String command = Serial.readStringUntil('\n');
        command.trim();
        
        // ============================================
        // COMANDI CALIBRAZIONE
        // ============================================
        
        if (command == "CAL_MAN?") {
            Serial.println("+------------------------------------------------------+");
            Serial.println("|           CALIBRAZIONE MANUALE - ISTRUZIONI          |");
            Serial.println("+------------------------------------------------------+");
            Serial.println("📌 SCOPO:");
            Serial.println("   Impostare manualmente il fattore di correzione del SI5351.\n");
            Serial.println("📋 PROCEDURA:");
            Serial.println("   1. RESETTA la calibrazione corrente: CAL_RESET");
            Serial.println("   2. Sintonizza il VFO su una frequenza precisa (es. 28.000.000 Hz)");
            Serial.println("   3. Misura la frequenza effettiva con un frequenzimetro");
            Serial.println("   4. Calcola il fattore: (Errore_Hz / Frequenza_target_Hz) × 1.000.000.000");
            Serial.println("   5. Invia il comando: CAL_MAN <valore>\n");
            Serial.println("📝 ESEMPIO:");
            Serial.println("   Target: 28.455.000 Hz (VFO + IF)");
            Serial.println("   Misurato: 28.454.710 Hz");
            Serial.println("   Errore: -290 Hz");
            Serial.println("   Fattore: (-290 × 1.000.000.000) / 28.455.000 = -10.193");
            Serial.println("   Comando: CAL_MAN -10193\n");
            Serial.println("⚠️  NOTA: Il segno del fattore può essere invertito sul tuo SI5351.");
            Serial.println("   Verifica con CAL_READ dopo l'impostazione.\n");
        }
        else if (command == "CAL_FREQ?") {
            Serial.println("+------------------------------------------------------+");
            Serial.println("|         CALIBRAZIONE AUTOMATICA - ISTRUZIONI         |");
            Serial.println("+------------------------------------------------------+");
            Serial.println("📌 SCOPO:");
            Serial.println("   Calibrare automaticamente il SI5351 misurando la frequenza.\n");
            Serial.println("📋 PROCEDURA:");
            Serial.println("   1. RESETTA la calibrazione corrente: CAL_RESET");
            Serial.println("   2. Sintonizza il VFO su una frequenza precisa (es. 28.000.000 Hz)");
            Serial.println("   3. Misura la frequenza effettiva con un frequenzimetro");
            Serial.println("   4. Invia: CAL_FREQ <frequenza_misurata>\n");
            Serial.println("📝 ESEMPIO:");
            Serial.println("   Frequenza target (VFO): 28.000.000 Hz");
            Serial.println("   Frequenza misurata: 28.454.710 Hz (VFO + IF)");
            Serial.println("   Comando: CAL_FREQ 28454710\n");
            Serial.println("✅ Il sistema calcolerà e applicherà il fattore di correzione.");
            Serial.println("   Verifica con CAL_READ dopo l'impostazione.\n");
        }
        else if (command.startsWith("CAL_MAN ")) {
            String valueStr = command.substring(8);
            valueStr.replace("<", "");
            valueStr.replace(">", "");
            long calValue = atol(valueStr.c_str());
            
            calibrateSI5351(calValue);
            eepromManager.saveCalibration(calValue);
            currentCalibration = calValue;
            
            Serial.print("✅ Calibrazione manuale applicata: ");
            Serial.println(calValue);
        }
        else if (command.startsWith("CAL_FREQ ")) {
            String freqStr = command.substring(9);
            freqStr.replace("<", "");
            freqStr.replace(">", "");
            long measuredFreq = atol(freqStr.c_str());
            
            long actualFreq = (long)displayedFrequency + (long)IF_FREQUENCY;
            long error = measuredFreq - actualFreq;
            long calValue = (long)(((long long)error * 1000000000LL) / actualFreq);
            
            Serial.println("\n=== CALIBRAZIONE AUTOMATICA ===");
            Serial.print("Target: "); Serial.print(actualFreq); Serial.println(" Hz");
            Serial.print("Misurato: "); Serial.print(measuredFreq); Serial.println(" Hz");
            Serial.print("Errore: "); Serial.print(error); Serial.println(" Hz");
            Serial.print("Fattore calcolato: "); Serial.println(calValue);
            
            calibrateSI5351(calValue);
            eepromManager.saveCalibration(calValue);
            currentCalibration = calValue;
            
            Serial.println("✅ Calibrazione automatica salvata.");
        }
        else if (command == "CAL_READ") {
            long readValue = 0;
            if (eepromManager.loadCalibration(readValue)) {
                currentCalibration = readValue;
                Serial.print("📊 Calibrazione corrente: ");
                Serial.println(currentCalibration);
            } else {
                Serial.println("❌ Nessuna calibrazione salvata");
            }
        }
        else if (command == "CAL_RESET") {
            calibrateSI5351(0);
            eepromManager.saveCalibration(0);
            currentCalibration = 0;
            Serial.println("🔄 Calibrazione resettata a 0");
        }
        else if (command == "HELP") {
            Serial.println("+------------------------------------------------------+");
            Serial.println("|              VFO-BFO RECEIVER - COMANDI               |");
            Serial.println("+------------------------------------------------------+");
            
            Serial.println("📌 COMANDI CALIBRAZIONE:\n");
            Serial.println("   CAL_MAN <valore>   - Imposta fattore manualmente");
            Serial.println("   CAL_MAN?           - Istruzioni calibrazione manuale");
            Serial.println("   CAL_FREQ <freq>    - Calibrazione automatica");
            Serial.println("   CAL_FREQ?          - Istruzioni calibrazione automatica");
            Serial.println("   CAL_READ           - Legge fattore corrente");
            Serial.println("   CAL_RESET          - Resetta calibrazione a 0\n");
            
            Serial.println("📌 ESEMPI:\n");
            Serial.println("   CAL_MAN -10193     - Imposta fattore -10193");
            Serial.println("   CAL_FREQ 28454710  - Calibra su 28.454.710 Hz");
            Serial.println("   CAL_READ           - Mostra fattore corrente\n");
            
            Serial.println("📌 ALTRI COMANDI:\n");
            Serial.println("   INFO               - Info sistema");
            Serial.println("   HELP               - Mostra questo aiuto\n");
            
            Serial.println("⚠️  IMPORTANTE:");
            Serial.println("   -La calibrazione è più precisa se effettuata su frequenze alte ");
            Serial.println("   (es. 28 MHz) e con un frequenzimetro preciso.");
            Serial.println("   -Prima di ogni calibrazione, resettare il fattore con CAL_RESET");
            Serial.println("   e verificare con CAL_READ prima di procedere.\n");
        }
        else if (command == "INFO") {
            Serial.println("\n=== VFO-BFO Receiver ===");
            Serial.print("📻 Frequenza: "); Serial.print(displayedFrequency); Serial.println(" Hz");
            Serial.print("📡 Modalità: "); Serial.println(modeNames[currentMode]);
            Serial.print("⚙️ Step: "); Serial.println(step);
            Serial.print("🔧 Calibrazione: "); Serial.println(currentCalibration);
            Serial.print("📶 BFO: "); Serial.println(bfoEnabled ? "ON" : "OFF");
            if (bfoEnabled) {
                Serial.print("   Frequenza BFO: "); Serial.println(bfoFrequency);
            }
            Serial.println();
        }
    }
}

// ============================================
// FUNZIONI INSERIMENTO FREQUENZA
// ============================================

void startFrequencyInput(char firstDigit) {
    inputMode = true;
    inputDisplay = "";
    inputValue = "";
    inputDisplay += firstDigit;
    inputValue += firstDigit;
    lastInputTime = millis();
    
    showFrequencyInputMode(true);
    updateFrequencyInputDisplay(inputDisplay);
    
    // ---------------------------------------------
    // DEBUG Modalità inserimento attivata e primo digit
    // ---------------------------------------------
    // Serial.print("Input mode: ");
    // Serial.println(inputValue);

}

void updateFrequencyInput(char digit) {
    if (!inputMode) return;
    
    lastInputTime = millis();
    
    if (digit >= '0' && digit <= '9') {
        // Aggiorna il valore reale (senza punti)
        if (inputValue.length() < 7) {
            inputValue += digit;
        } else {
            return;
        }
        
        // Costruisci la stringa per il display con punti automatici
        inputDisplay = "";
        for (int i = 0; i < inputValue.length(); i++) {
            inputDisplay += inputValue[i];
            if (i == 1 && inputValue.length() > 2) {
                inputDisplay += ".";   // Primo punto dopo 2 cifre
            }
            if (i == 4 && inputValue.length() > 5) {
                inputDisplay += ".";   // Secondo punto dopo 5 cifre
            }
        }
    }
    
    updateFrequencyInputDisplay(inputDisplay);

    // ---------------------------------------------
    // DEBUG frequenza inserita e visualizzata
    // ---------------------------------------------
    // Serial.print("Display: ");
    // Serial.println(inputDisplay);
    // Serial.print("Value: ");
    // Serial.println(inputValue);

}

void confirmFrequencyInput() {
    if (!inputMode) return;
    
    int len = inputValue.length();
    unsigned long newFreq = 0;
    
    if (len == 2) {
        // "14" → 14.000.000 Hz
        newFreq = inputValue.toInt() * 1000000UL;
    }
    else if (len >= 4 && len <= 7) {
        // Prime 2 cifre = MHz
        String mhzStr = inputValue.substring(0, 2);
        unsigned long mhz = mhzStr.toInt();
        
        // Cifre successive
        String restStr = inputValue.substring(2);
        
        // kHz (prime 3 cifre del resto)
        unsigned long khz = 0;
        if (restStr.length() >= 1) {
            String khzStr = restStr.substring(0, min(3, (int)restStr.length()));
            khz = khzStr.toInt();
            if (khzStr.length() == 1) khz *= 100;
            else if (khzStr.length() == 2) khz *= 10;
        }
        
        // Decine di Hz (cifre rimanenti dopo i kHz)
        unsigned long tensHz = 0;
        if (restStr.length() > 3) {
            String tensStr = restStr.substring(3);
            tensHz = tensStr.toInt();
            if (tensStr.length() == 1) tensHz *= 10;
        }
        
        newFreq = mhz * 1000000UL + khz * 1000UL + tensHz * 10UL;
        
        // ---------------------------------------------
        // DEBUG parsing frequenza da input
        // ---------------------------------------------
        // Serial.print("restStr: ");
        // Serial.println(restStr);
        // Serial.print("kHz: ");
        // Serial.println(khz);
        // Serial.print("tensHz: ");
        // Serial.println(tensHz);
    }
    
        // ---------------------------------------------
        // DEBUG input frequenza
        // ---------------------------------------------
        // Serial.print("Input value: ");
        // Serial.println(inputValue);
        // Serial.print("Frequenza (Hz): ");
        // Serial.println(newFreq);

    if (newFreq >= 1000000 && newFreq <= 30000000) {
        displayedFrequency = newFreq;
        vfoFrequency = displayedFrequency + IF_FREQUENCY;
        updateFrequency();
        updateBandInfo();
         eepromManager.requestQuickSave();
        showInputConfirm();
    } else {
        
        // ---------------------------------------------
        // DEBUG frequenza non valida
        // ---------------------------------------------
        // Serial.println("Frequenza non valida!");

        showInputError();  
    }
    
    inputMode = false;
    inputDisplay = "";
    inputValue = "";
}

void forceExitInputMode() {
    if (!inputMode) return;

    // Salva lo stato corrente del TFT
    uint8_t savedFont = tft.textfont;
    uint8_t savedSize = tft.textsize;
    
    inputMode = false;
    inputDisplay = "";
    inputValue = "";
    
    // Rigenera l'intera area frequenza
    tft.fillRect(VFO_DISPLAY_X, VFO_DISPLAY_Y, 250, 60, BACKGROUND_COLOR);
    
    // Ridisegna la frequenza direttamente senza sprite
    tft.setTextColor(FREQUENCY_COLOR, BACKGROUND_COLOR);
    tft.setTextFont(7);
    tft.setTextSize(0);
    tft.setCursor(VFO_DISPLAY_X , VFO_DISPLAY_Y +5 );
    tft.print(formatFrequency(displayedFrequency));

    // Ripristina lo stato salvato
    tft.setTextFont(savedFont);
    tft.setTextSize(savedSize);
    
    // ---------------------------------------------
    // DEBUG uscita forzata da modalità inserimento
    // ---------------------------------------------
    // Serial.println("Uscita forzata - Display ripristinato");
}

void cancelFrequencyInput() {
    if (!inputMode) return;
    
    inputMode = false;
    inputDisplay = "";
    inputValue = "";
    updateFrequencyDisplay();
    
    // ---------------------------------------------
    // DEBUG input annullato
    // ---------------------------------------------    
    // Serial.println("Input annullato");
}

void checkInputTimeout() {
    if (inputMode && (millis() - lastInputTime > INPUT_TIMEOUT)) {

    forceExitInputMode();

    // ---------------------------------------------
    // DEBUG timeout inserimento frequenza
    // ---------------------------------------------                
    // Serial.println("Input timeout");

    }
}
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
void loop() {

  readVFOEncoder();

  // Gestione Pitch BFO
  static int lastBFOOffset = 0;
  updateBFOFromEncoder();
  
  if (currentBFOOffset != lastBFOOffset) {
    drawBFODisplay();
    lastBFOOffset = currentBFOOffset;
  }

  // Gestione comandi seriali
  handleSerialCommands();

  // ============================================
  // GESTIONE PULSANTI 
  // ============================================
  
  // Pulsante STEP
  {
    static bool stepButtonPressed = false;
    static unsigned long lastStepButtonPress = 0;
    
    if (digitalRead(SW_STEP) == LOW && !stepButtonPressed) {
      if (millis() - lastStepButtonPress > buttonDebounce) {
        stepButtonPressed = true;
        changeStep();
        lastStepButtonPress = millis();
        updateStepDisplay();
        eepromManager.requestQuickSave();
        delay(300);
      }
    }  
    if (digitalRead(SW_STEP) == HIGH && stepButtonPressed) {
      stepButtonPressed = false;
    }
  }

  // Pulsante BANDA
  {
    static bool bandButtonPressed = false;
    static unsigned long lastBandButtonPress = 0;
    
    if (digitalRead(SW_BAND) == LOW && !bandButtonPressed) {
      if (millis() - lastBandButtonPress > buttonDebounce) {
        bandButtonPressed = true;
        changeBand();
        lastBandButtonPress = millis();
        updateFrequency();
        updateFrequencyDisplay();
        updateBandInfo();
        eepromManager.requestQuickSave();
        delay(300);
      }
    } 
    if (digitalRead(SW_BAND) == HIGH && bandButtonPressed) {
      bandButtonPressed = false;
    }
  }

  // Pulsante MODALITA'
  {
    static bool modeButtonPressed = false;
    static unsigned long lastModeButtonPress = 0;
    
    if (digitalRead(SW_MODE) == LOW && !modeButtonPressed) {
      if (millis() - lastModeButtonPress > buttonDebounce) {
        modeButtonPressed = true;
        changeMode();
        lastModeButtonPress = millis();
        updateModeOutputs();
        updateModeInfo();
        eepromManager.requestQuickSave();
        delay(300);
      }
    } 
    if (digitalRead(SW_MODE) == HIGH && modeButtonPressed) {
      modeButtonPressed = false;
    }
  }

  // Gestione pulsante AGC
  checkAGCButton();

  // Gestione pulsante ATT
  checkATTButton();

  // Aggiorna S-meter ogni 50ms
  static unsigned long lastSMeterUpdate = 0;
  if (millis() - lastSMeterUpdate > 50) {
    updateSMeter();
    lastSMeterUpdate = millis();
  }

  // Gestione salvataggio EEPROM
  eepromManager.update();
  
  // Gestione tastiera a matrice 4x4 (solo se presente)
    if (isKeypadAvailable()) {
        handleKeypad();
        
        char key = getLastKey();
        if (key != '\0') {
            if (inputMode) {
                // Siamo in modalità inserimento frequenza
                if (key >= '0' && key <= '9') {
                    updateFrequencyInput(key);
                } else if (key == 'A' || key == 'a') {
                    confirmFrequencyInput();
                } else if (key == 'C' || key == 'c' || key == '#') {
                    cancelFrequencyInput();
                }
            } else {
                // Modalità normale
                switch (key) {
                    case '*':
                        // Step Down
                        if (step == 10) step = 10000;
                        else if (step == 100) step = 10;
                        else if (step == 1000) step = 100;
                        else if (step == 10000) step = 1000;
                        updateStepDisplay();
                        // Debug
                        // Serial.print("Step: ");
                        // Serial.println(step);
                        break;
                        
                    case '#':
                        // Step Up
                        if (step == 10) step = 100;
                        else if (step == 100) step = 1000;
                        else if (step == 1000) step = 10000;
                        else if (step == 10000) step = 10;
                        updateStepDisplay();
                        // Debug
                        // Serial.print("Step: ");
                        // Serial.println(step);
                        break;
                        
                    case 'A':
                    case 'a':
                        Serial.println("Tasto A: funzione futura");
                        break;
                        
                    case 'B':
                    case 'b':
                        Serial.println("Tasto B: funzione futura");
                        break;
                        
                    case 'C':
                    case 'c':
                        Serial.println("Tasto C: funzione futura");
                        break;
                        
                    case 'D':
                    case 'd':
                        Serial.println("Tasto D: funzione futura");
                        break;
                        
                    default:
                        if (key >= '0' && key <= '9') {
                            startFrequencyInput(key);
                        }
                        break;
                }
            }
            resetLastKey();
        }
    }
    
    // Controllo timeout modalità input
    checkInputTimeout();

}

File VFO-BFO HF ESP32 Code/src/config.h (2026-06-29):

#ifndef CONFIG_H
#define CONFIG_H

#include <Arduino.h>

    // ============================================
    // VERSIONI PROGETTO
    // ============================================

        #define SW_VERSION "V2.0"
        #define HW_VERSION "V1.1"
        #define VERSION_DATE "Giugno 2026"

        #define AUTHOR "Scorpione Maker (IV3LDJ)"
        #define GITHUB_URL "https://github.com/loscorpione/VFO-BFO-HF-ESP32-Si5351"
        #define YOUTUBE_URL "https://youtube.com/@ScorpioneMaker"

        /*
        *  Descrizione  :
        *    Generatore VFO/BFO per ricevitori HF (1-30 MHz) basato su ESP32 e SI5351.
        *    Supporta encoder ottico/meccanico, display TFT, calibrazione automatica via serial monitor, 
        *    funzioni AGC Fast/Slow, attenuatore -20dB, pitch BFO regolabile, visualizzazione S-meter, 
        *    gestione bande e modalità, salvataggio configurazioni su EEPROM esterna.
        *  
        *  Licenza    : MIT
        */

    // ============================================
    // CONFIGURAZIONE ENCODER VFO
    // ============================================

        // Tipo encoder: OPTICAL o MECHANICAL
        #define ENCODER_TYPE_OPTICAL 1
        #define ENCODER_TYPE_MECHANICAL 0

        // === CAMBIA QUI IL TIPO DEL TUO ENCODER ===
        #define ENCODER_TYPE ENCODER_TYPE_OPTICAL   // Per ottico 
        //#define ENCODER_TYPE ENCODER_TYPE_MECHANICAL   // Per meccanico

        // Pin encoder VFO
        #define VFO_ENC_CLK 35
        #define VFO_ENC_DT  34

        // Parametri specifici per tipo
        #if ENCODER_TYPE == ENCODER_TYPE_OPTICAL
            // Encoder Ottico 400PPR
            #define ENCODER_PPR 400
            #define ENCODER_ATTACH_MODE attachSingleEdge   // 400 conteggi/giro × 10Hz = 4000 Hz/giro
            //#define ENCODER_ATTACH_MODE attachHalfQuad   // 800 conteggi/giro x 10Hz = 8000 Hz/giro (più veloce)
            //#define ENCODER_ATTACH_MODE attachFullQuad   // 1600 conteggi/giro x 10Hz = 16000 Hz/giro (molto veloce, sconsigliato per ottico)

        #else
            // Encoder Meccanico 30PPR
            #define ENCODER_PPR 24
            #define ENCODER_ATTACH_MODE attachFullQuad     // 120 conteggi/giro × 10Hz = 1200 Hz/giro
            
        #endif

        // Sensibilità encoder VFO
        // Riduce la sensibilità: 1 = originale, 2 = metà, 4 = un quarto
        #define ENCODER_SENSITIVITY_DIVIDER 4

        
        // CONFIGURAZIONE STEP VFO
        #define STEP_10HZ 10
        #define STEP_100HZ 100
        #define STEP_1KHZ 1000
        #define STEP_10KHZ 10000
        
    // ============================================
    // CONFIGURAZIONE ENCODER BFO
    // ============================================

        #define BFO_ENC_CLK 12               // Pin CLK dell'encoder BFO
        #define BFO_ENC_DT  13               // Pin DT dell'encoder BFO
        #define ENCODER_BFO_DEBOUNCE_MS 4   // Debounce in millisecondi
        #define ENCODER_DIVIDER_BFO     4    // Impulsi necessari per un passo
        

    // ============================================
    // CONFIGURAZIONE PULSANTI
    // ============================================

        #define SW_STEP 32                  // Pulsante cambio Step VFO
        #define SW_BAND 33                  // Pulsante cambio banda
        #define SW_MODE 25                  // Pulsante cambio modalità
        #define SW_AGC  26                  // Pulsante AGC Fast/Slow
        #define SW_ATT  27                  // Pulsante Attenuatore -20dB
        #define SW_SCAN 14                  // Pulsante Scan (futuro)
        #define SW_RTTY_CW  36              // Pulsante RTTY_CW (futuro)

        // Debounce per tutti i pulsanti
        const int buttonDebounce = 200;

    // ============================================
    // CONFIGURAZIONE TASTIERA MATRICE 4x4 (I2CKeyPad)
    // ============================================

        // Indirizzo I2C del modulo PCF8574T
        #define KEYPAD_I2C_ADDR 0x22

        // Debounce in millisecondi
        #define KEYPAD_DEBOUNCE_MS 50   

        // Timeout in millisecondi
        #define FREQ_INPUT_TIMEOUT 5000   // Timeout in millisecondi

    // ============================================
    // CONFIGURAZIONE INPUT/OUTPUT VARI
    // ============================================

        // Configurazione GPIO Ingresso S-Meter 
        #define S_METER_PIN 15              // Pin analogico per il S-meter
            
        // Configurazione GPIO Ingresso RTTY_CW 
        #define RTTY_CW_PIN 4               // Pin digitale per RTTY_CW (futuro)

        // Configurazione GPIO bus I2C 
        #define I2C_SCL 21                  // Pin SCL I2C
        #define I2C_SDA 22                  // Pin SDA I2C

    // ============================================
    // CONFIGURAZIONE PCF8574A
    // ============================================
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

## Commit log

2025-10-07 Aggiunto pitch BFO
2025-10-13 Inserito BFO con regolazione del pitch
2025-10-18 Aggiunto Calibrazione SI5351 (Da monitor seriale)
    Comandi calibrazione SI5351:
    CAL <valore> - Imposta calibrazione (es: CAL 1250)
    CAL_READ - Legge calibrazione corrente
    CAL_RESET - Resetta calibrazione a 0
    HELP - Mostra questo aiuto
    INFO - Informazioni sistema
    [DigiOUT.cpp, EEPROM_manager.cpp, PLL.cpp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]
2025-11-12 Insert circuit
    [VFO BFO Si5351.kicad_pcb, VFO BFO Si5351.kicad_sch]
2025-12-12 Circuiti e PCB ver.1.0
    [Front Pannel-B_Cu.gbr, Front Pannel-B_Mask.gbr, Front Pannel-B_Paste.gbr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]
2026-02-27 Aggiornamento Gerber main board
    [VFO BFO Si5351-B_Cu.gbr, VFO BFO Si5351-B_Mask.gbr, VFO BFO Si5351-B_Paste.gbr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]
2026-03-18 PDF distenta componenti e schemi elettrico e di montaggio
    [Front Pannel-B_Cu.gbr, Front Pannel-B_Mask.gbr, Front Pannel-B_Paste.gbr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]
2026-04-01 Errata corrige: schermo bianco dopo il caricamento del Firmware
    difetto dello schermo bianco dopo il caricamento del Firmware
    la definizione dei pin risiede in User_Setups/Setup42_ILI9341_ESP32.h prima di questo aggiornamento la libreria era scaricata da .pio\libdeps\esp32dev quindi le mie impostazioni mancavano. ora la libreria e le impostazioni personalizzate risiedono in /lib .
2026-05-19 Aggiunto STEP Front pannel
    [Front Pannel.step]
2026-06-02 Miglioramenti encoder e stabilizzazione VFO/BFO
    - Implementato ESP32Encoder con supporto PCNT (nessun impulso perso)
    - Aggiunto divisore di sensibilità con accumulo residui
    - Supporto selezionabile per encoder ottico (400 PPR) e meccanico (30 PPR)
    - Aggiunta schermata di avvio con logo e info I2C
    - Completata calibrazione SI5351 via seriale
    - Bugfix vari e pulizia codice"
    [VFO_BFO.cpp, config.h, display.cpp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]
2026-06-29 Versione 2.0
    - Implementato supporto encoder ottico/meccanico con ESP32Encoder (PCNT)
    - Aggiunta tastiera a matrice 4x4 con PCF8574T per inserimento frequenza
    - Calibrazione SI5351 automatica (CAL_FREQ) e manuale (CAL_MAN)
    - Inserimento frequenza da tastiera con visualizzazione temporanea
    - Salvataggio configurazioni in EEPROM (frequenza, step, banda, modalita)
    - Help completo via seriale con istruzioni calibrazione
    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
